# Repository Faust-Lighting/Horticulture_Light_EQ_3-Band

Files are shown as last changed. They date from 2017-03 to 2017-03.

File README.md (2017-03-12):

# Faust Lighting EQ 3-Band Horticulture Light 
[Faust Lighting](http://faustlighting.com/)

EQ is a Wifi enabled 2ft linear grow light.  The light spectrum and on/off schedule can be customized for specific plant species by programming the 3-band LED module.  A durable powder-coated heat sink ensures long lasting performance in demanding environments, while the beautiful walnut trim allows EQ to blend seamlessly into your home decor. 

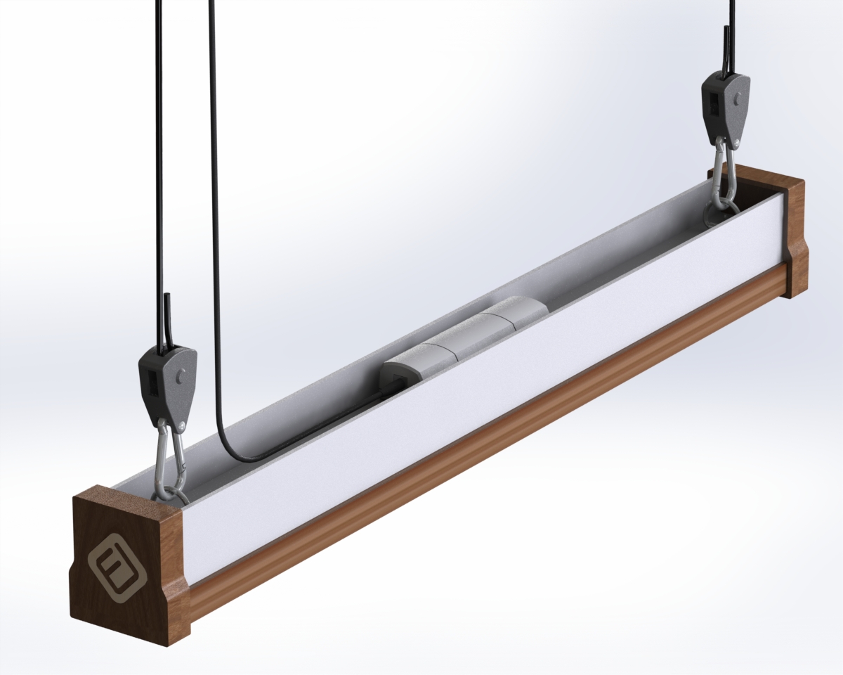
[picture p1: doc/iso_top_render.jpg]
Iso Render

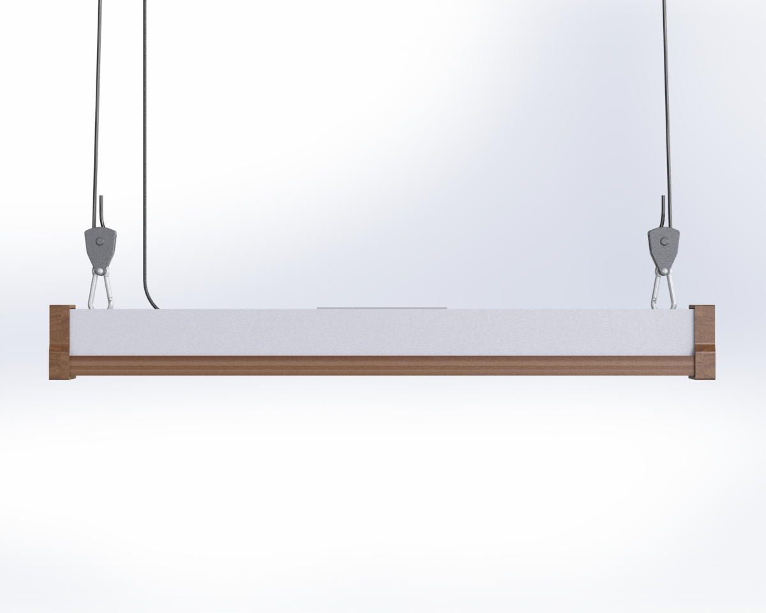
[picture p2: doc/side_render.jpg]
Side Render

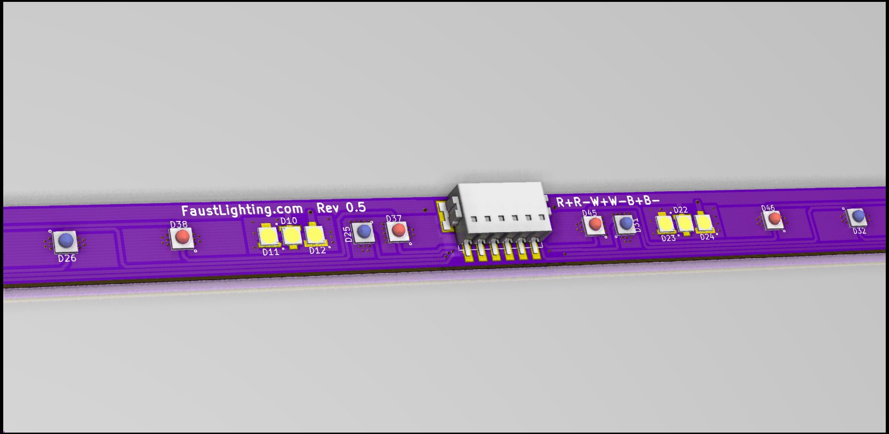
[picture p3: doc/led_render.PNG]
LED Render

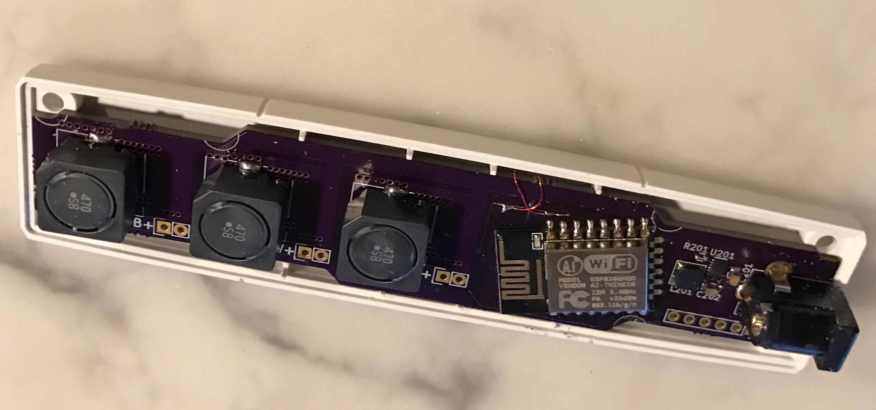
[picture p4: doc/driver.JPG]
Driver Photo


**Features**

* Tunable 3-Band Spectrum
* Red:  660nm
* Blue:  450nm
* White:  3000K CCT 90 CRI
* WiFi Connectivity
* No hub required
* Programmable Scheduling
* Simple scheduling for on/off control
* Advanced event driven scheduling for plant growth stages
* Open Source Design
* Open software
* Open hardware

**Construction**

* Extruded aluminum heatsink with durable powdercoat finish
* Walnut trim accents and endcaps with clear satin finish
* High efficiency acrylic diffuser
* Adjustable rope ratchet hangers
* Impact resistant ABS enclosure for driver electronics

**Specifications**

* Input Voltage:  90-265VAC, 50/60Hz
* Power Consumption:  40W typical (varies with spectrum)
* Dimensions:  24.98" (L) x 2.63" (W) x 2.81" (H)
* Weight:  3.0 lbs

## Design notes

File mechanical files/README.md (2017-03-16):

# Mechanical Change Log 
[Faust Lighting](http://faustlighting.com/)

**ASM1001**
* Current Revision: 0.2
  * Change Description: Moved wire routing slot on EXT1003, replaced model of HSG1001 with the manufacturer provided model.

* Previous Revision: 0.1
  * Change Description: Initial GitHub release.

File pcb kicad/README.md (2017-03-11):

# PCB Change Log 
[Faust Lighting](http://faustlighting.com/)

**Driver Board**
* Current Revision 0.4

**LED Board**
* Current Revision 0.6

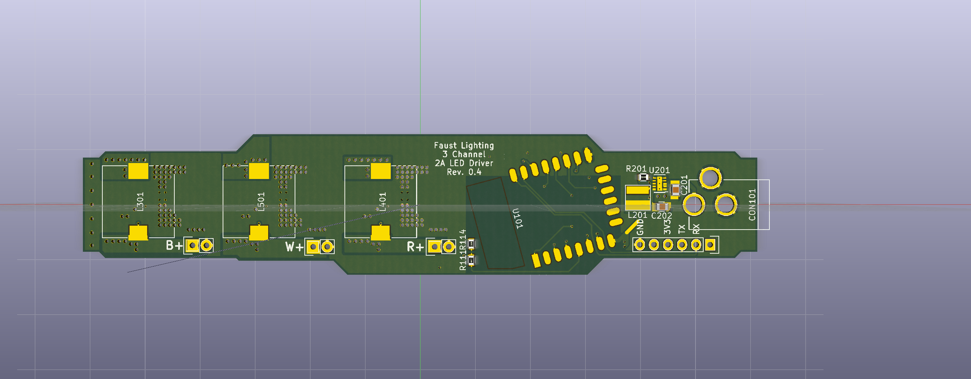
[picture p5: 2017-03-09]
pcb kicad/led_driver/3 channel led driver rev 0.4/top render.png

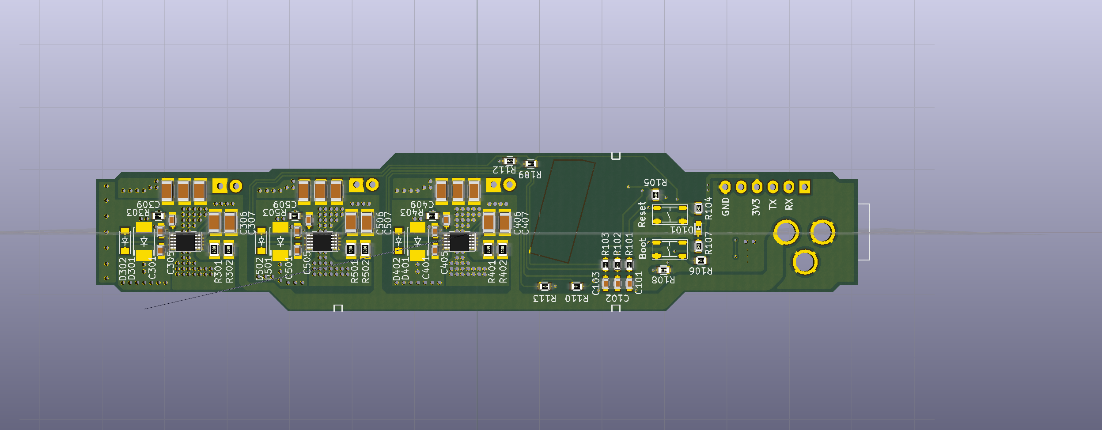
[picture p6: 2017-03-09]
pcb kicad/led_driver/3 channel led driver rev 0.4/bottom render.png

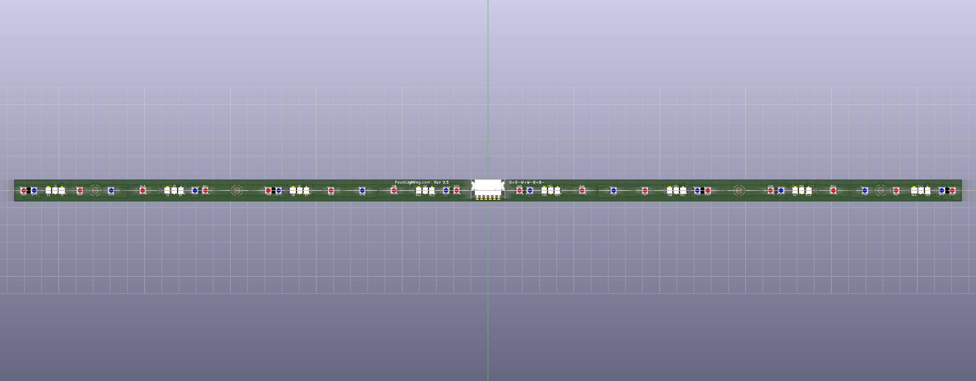
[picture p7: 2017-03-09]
pcb kicad/led_emitters/led emitter rev 0.6/light/front render.png

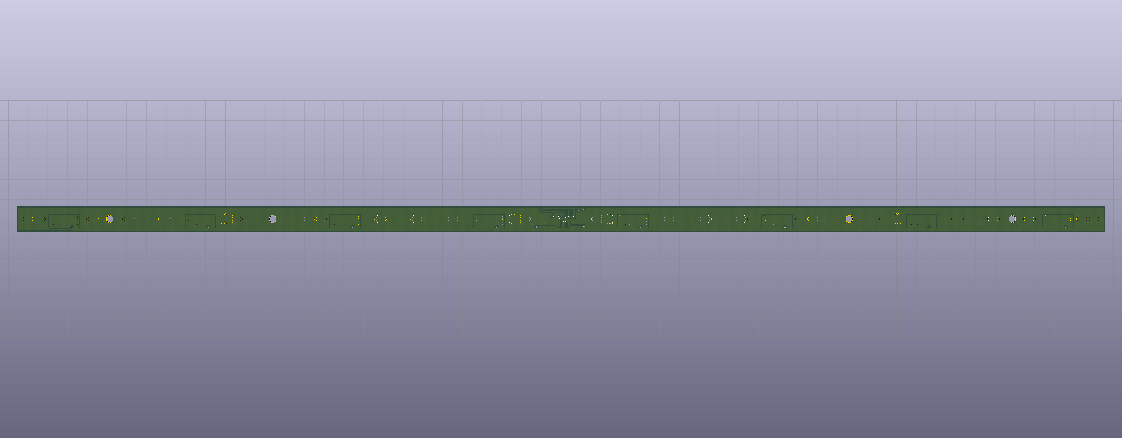
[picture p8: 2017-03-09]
pcb kicad/led_emitters/led emitter rev 0.6/light/back render.png

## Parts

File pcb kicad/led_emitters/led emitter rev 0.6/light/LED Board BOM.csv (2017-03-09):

Title | Grow Light - LED Board | Ref | Qty | Value | Footprint | Manufacturer | Manufacturer_Part_# | Mouser_Part_#
Revision | 0.5 | D1 D2 D3 D4 D5 D6 D7 D8 D9 D10 D11 D12 D15 D14 D13 D16 D17 D18 D21 D20 D19 D22 D23 D24 | 24 | White_LED | junes:MP3030 | Luminus | MP-3030-2200-30-90 | 896-MP303022003090
Date | 1/20/2017 | D37 D38 D39 D40 D41 D42 D43 D44 D45 D46 D47 D48 D49 D50 D51 D52 | 16 | Deep Red 660nm | junes:Deep_Red_660nm | Luminus | SST-10-DR-B90-H660 | 896-SST10DRB90H660
Generated | 1/19/2017 23:50 | D25 D26 D27 D28 D29 D30 D31 D32 D33 D34 D35 D36 | 12 | Blue 450nm | junes:Blue_450nm | Luminus | SST-10-B-B90-P450 | 896-SST10BB90P450
Company | Faust Light | P1 | 1 | CONN_02X03 | junes:1814676 | Phoenix Contact | 1814676 | 651-1814676
Comment 1
Comment 2
Comment 3
Comment 4
Total Parts | 53
Total Unique Parts | 4
Generated 1/19/2017 11:50:32 PM

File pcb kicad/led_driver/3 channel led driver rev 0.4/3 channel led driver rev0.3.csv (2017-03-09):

Title | ESP-8226 Controlled 3 Channel Led Driver 2A Max
Revision | 0.5
Date
Generated | 1/24/2017 15:12
Company
Comment 1
Comment 2
Comment 3
Comment 4
Total Parts | 70
Total Unique Parts | 25
Ref | Qty | Value | Footprint | Manufacturer | Manufacturer_Part_# | Mouser_Part_# | Notes
C101 C102 C103 | 3 | 10uF | Capacitors_SMD:C_0603 | Murata Electronics | GRM188R60J106KE47D | 81-GRM188R60J106KE7D | 6.3V X5R 10%
C201 | 1 | 2.2uF | Capacitors_SMD:C_0805 | Murata Electronics | GRM21BR61E225KA12L | 81-GRM21R61E225KA12L | 25V X5R 10%
C202 | 1 | 22.0uF | Capacitors_SMD:C_0805 | Murata Electronics | 81-GRM21R60J226ME39L | 81-GRM21R60J226ME39L | 6.3V X5R 20%
C301 C401 C501 | 3 | 0.1uF | Capacitors_SMD:C_0603 | Murata | GCM188R71C104KA37J | 81-GCM188R71C104KA7J | 16V X7R 10%
C309 C409 C509 | 3 | 470pF | Capacitors_SMD:C_0603 | Murata Electronics | GRM033R71H471KA12D | 81-GRM033R71H471KA2D | 50V X7R 10%
C305 C405 C505 | 3 | 1uF | Capacitors_SMD:C_0603 | Murata | GCM188R71C105KA64D | 81-GCM188R71C105K64D | 16V X7R 10%
C306 C307 C302 C303 C304 C406 C407 C402 C403 C404 C506 C507 C502 C503 C504 | 15 | 2.2uF | Capacitors_SMD:C_0805 | Murata Electronics | GRM21BR61E225KA12L | GRM21BR61E225KA12L | 25V X5R 10%
CON101 | 1 | BARREL_JACK | junes:Barrel_Jack_Wurth_694106301002 | Wurth Electronics | 6.94106E+11 | 710-694106301002
D101 | 1 | LED | LEDs:LED-0603 | Lite-On | LTST-C190KRKT | 859-LTST-C190KRKT
D302 D402 D502 | 3 | 100V 200mA | Diodes_SMD:SOD-123 | ON Semi | MMSD4148T1G | 863-MMSD4148T1G | 100V 0.2A
D301 D401 D501 | 3 | 100V 3A | Diodes_SMD:SOD-128-2 | NXP | PMEG10030ELPX | 771-PMEG10030ELPX | 100V 3A
L201 | 1 | 10uH | junes:VLS4012ET-100M | TDK | VLS4012ET-100M | 810-VLS4012ET-100M | 20% 500mA+ 228mOhms
L301 L401 L501 | 3 | 47uH | junes:MBH12575C | Murata - TOKO | MBH12575C-470MA=P3 | 81-MBH12575C-470MAP3 | 2.7A 53mOhms 20%
P101 | 1 | CONN_01X06 | Pin_Headers:Pin_Header_Straight_1x06
P1 P2 P3 | 3 | CONN_01X02 | Pin_Headers:Pin_Header_Straight_1x02
R101 R102 R107 R103 | 4 | 1K | Resistors_SMD:R_0603
R104 R105 R106 | 3 | 10K | Resistors_SMD:R_0603
R108 | 1 | 10K | Resistors_SMD:R_0603
R201 | 1 | 100K | Resistors_SMD:R_0603 |  |  |  | 1% Tolerence
R302 R301 R402 R401 R502 R501 | 6 | 0.27 | Resistors_SMD:R_0805 | Susumu | KRL1220E-M-R270-F-T5 | 754-KRL1220EMR270FT5 | 1%
R303 R403 R503 | 3 | 48.7k | Resistors_SMD:R_0603 | Vishay | CRCW060348K7FKEA | 71-CRCW0603-48.7K-E3 | 1%
SW102 SW101 | 2 | TACT_4.2MM | MF_Switches:MF_Switches-TACT4.2MM | C&K Components | PTS810 SJK 250 SMTR LFS | 611-PTS810SJK250SMTR
U101 | 1 | ESP8266-12E | ESP8266:ESP-12E | ESPRESSIF | ESP8266-12E | 485-2491
U201 | 1 | TPS62177 | junes:TPS62177 | Texas Instruments | TPS62177DQCR | 595-TPS62177DQCR
U301 U401 U501 | 3 | TPS92515 | junes:TPS92515x | Texas Instruments | TPS92515DGQR | 595-TPS92515DGQR
BOM made with KICAD_BOM_WIZARD (https://github.com/HashDefineElectronics/KiCad_BOM_Wizard.git)
Generated 1/24/2017 3:12:45 PM

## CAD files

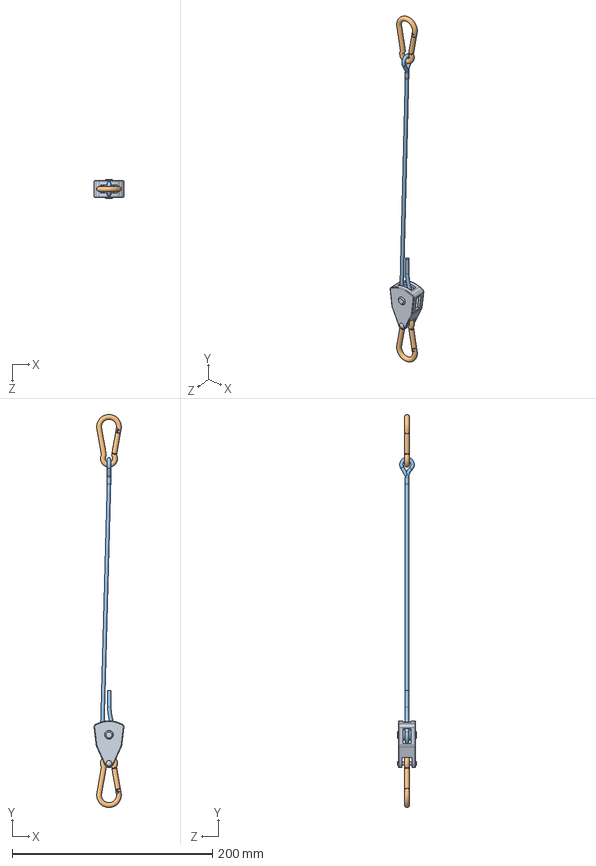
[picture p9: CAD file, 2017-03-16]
mechanical files/asm1001 rev 0.2/ASM1001 Rev 0.2 SOLIDWORKS/MIS1003.SLDASM
29.9 x 393.0 x 19.3 mm
MIS1003-2
MIS1003-3 x 2
MIS1003-1

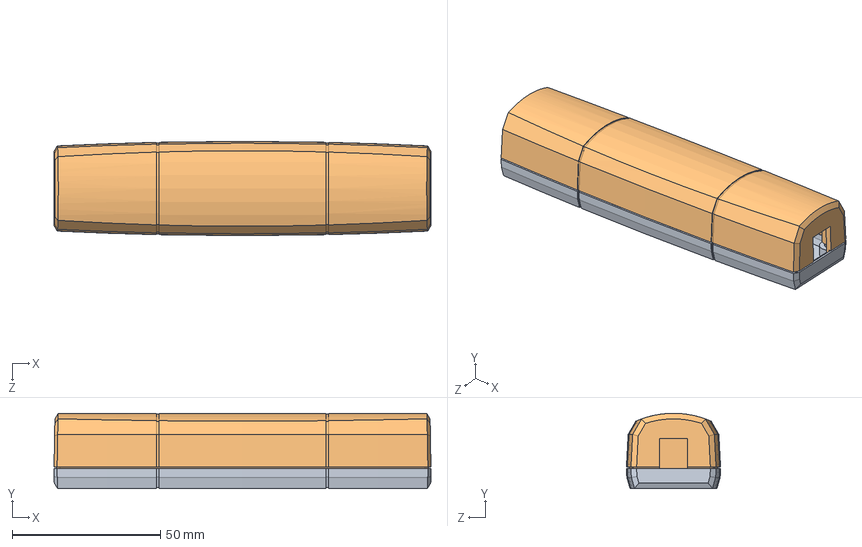
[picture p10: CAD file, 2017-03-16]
mechanical files/asm1001 rev 0.2/ASM1001 Rev 0.2 SOLIDWORKS/HSG1001.SLDASM
127.0 x 25.4 x 31.8 mm
HSG1001-1
HSG1001-2

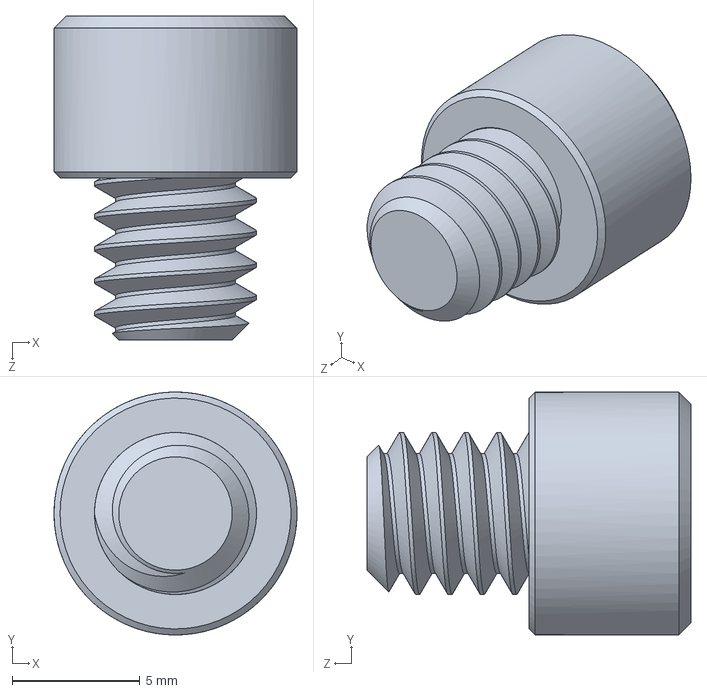
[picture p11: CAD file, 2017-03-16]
mechanical files/asm1001 rev 0.2/ASM1001 Rev 0.2 SOLIDWORKS/FST1002.SLDPRT
9.53 x 9.52 x 12.7 mm

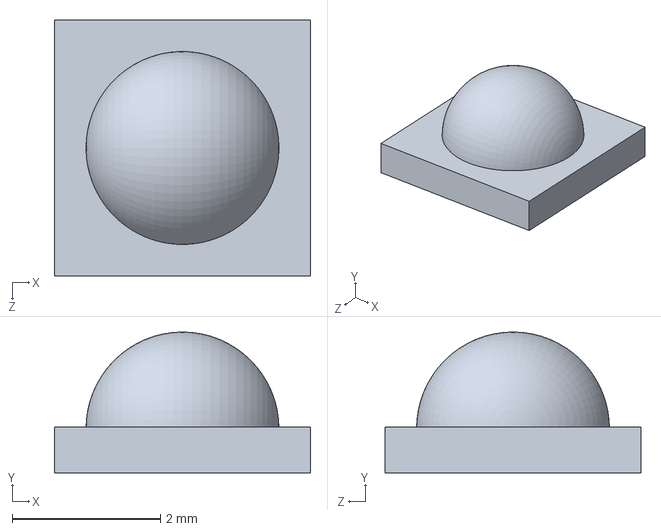
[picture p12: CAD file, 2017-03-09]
pcb kicad/led_emitters/led emitter rev 0.6/3D files/red led.SLDPRT
3.45 x 1.90 x 3.45 mm

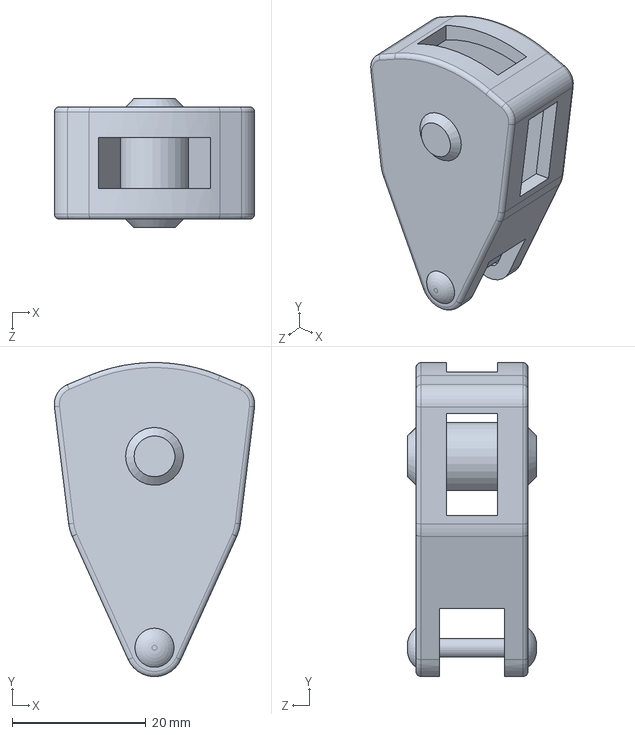
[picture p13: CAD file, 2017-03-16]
mechanical files/asm1001 rev 0.2/ASM1001 Rev 0.2 SOLIDWORKS/MIS1003-2.SLDPRT
29.9 x 46.9 x 19.3 mm

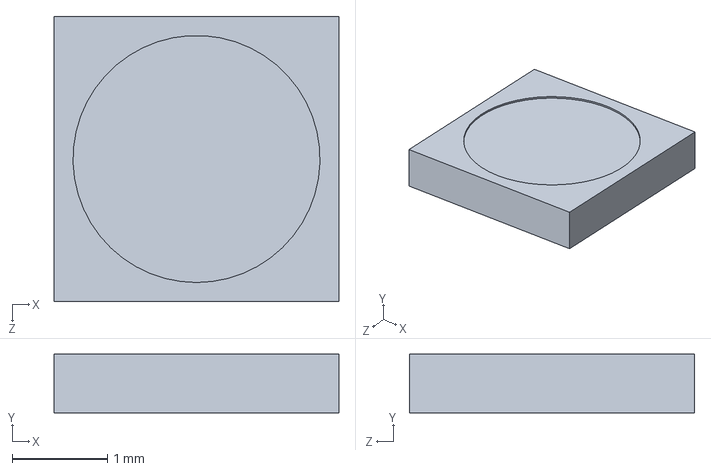
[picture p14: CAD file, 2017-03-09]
pcb kicad/led_emitters/led emitter rev 0.6/3D files/white led.SLDPRT
3.00 x 0.62 x 3.00 mm

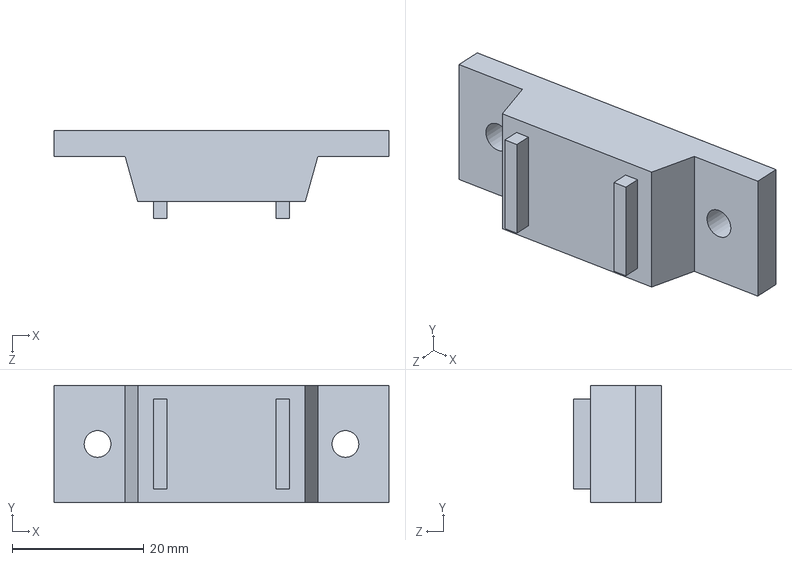
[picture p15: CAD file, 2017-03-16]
mechanical files/asm1001 rev 0.2/ASM1001 Rev 0.2 SOLIDWORKS/MIS1001.SLDPRT
50.8 x 17.8 x 13.3 mm

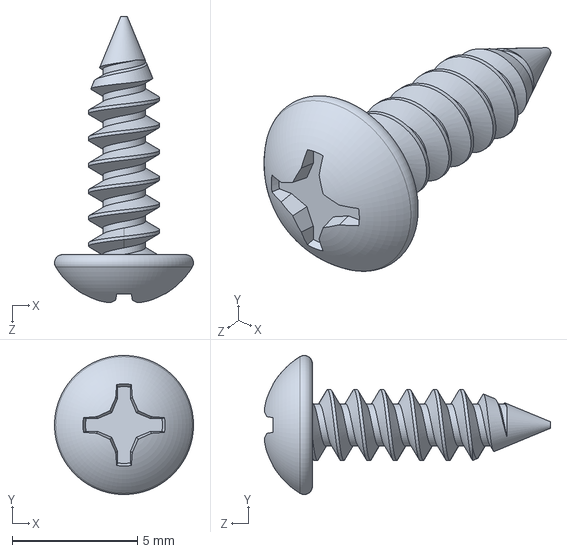
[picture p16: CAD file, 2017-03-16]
mechanical files/asm1001 rev 0.2/ASM1001 Rev 0.2 SOLIDWORKS/FST1004.SLDPRT
5.56 x 5.56 x 11.5 mm

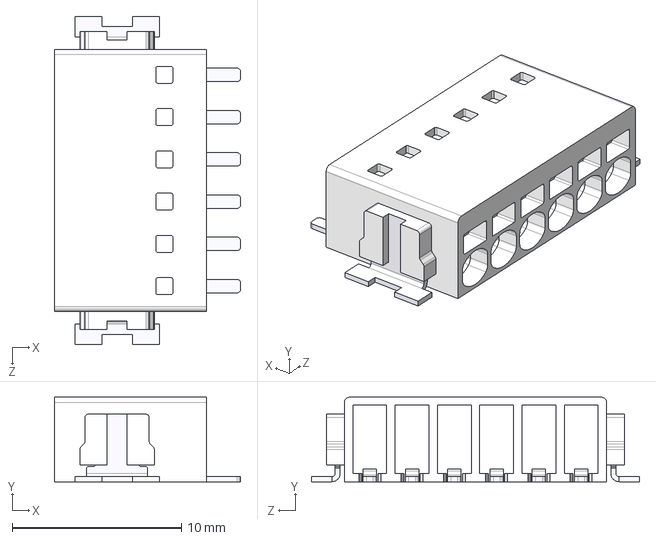
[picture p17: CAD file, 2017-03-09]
pcb kicad/led_emitters/led emitter rev 0.6/3D files/PHOENIX CONTACT 1814676.STEP
11.0 x 5.00 x 19.4 mm

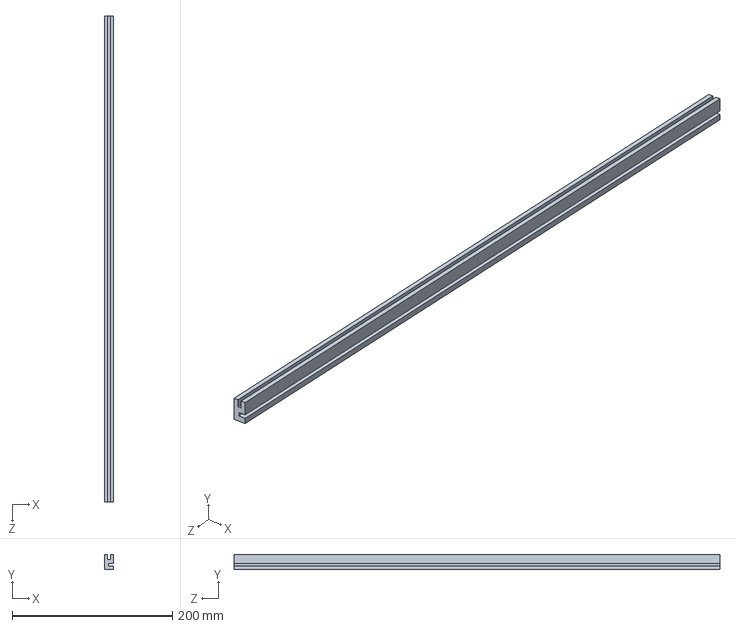
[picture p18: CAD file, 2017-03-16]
mechanical files/asm1001 rev 0.2/ASM1001 Rev 0.2 SOLIDWORKS/EXT1005.SLDPRT
11.1 x 19.1 x 606.4 mm

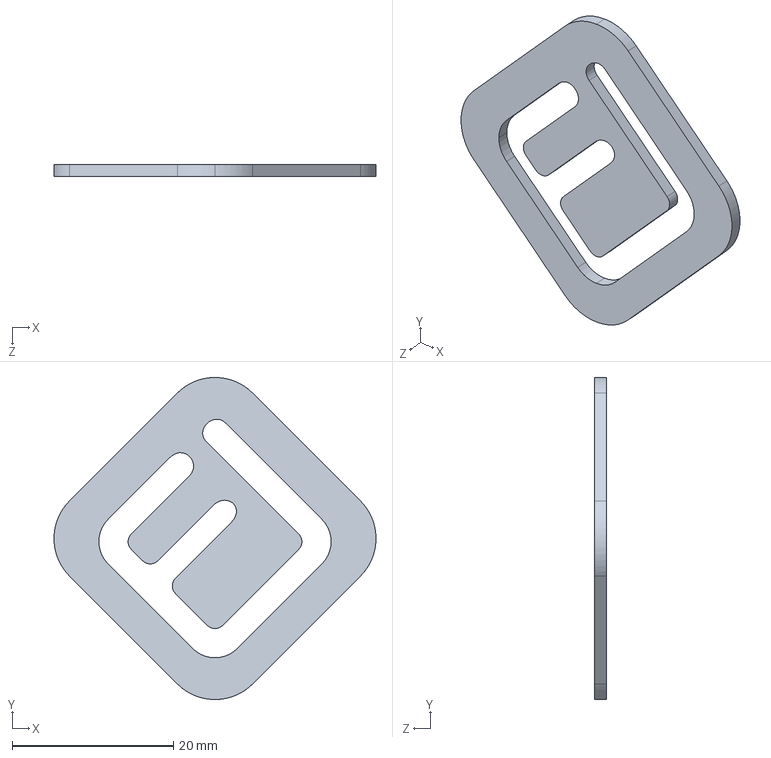
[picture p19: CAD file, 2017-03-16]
mechanical files/asm1001 rev 0.2/ASM1001 Rev 0.2 SOLIDWORKS/COV1002.SLDPRT
39.9 x 39.9 x 1.52 mm

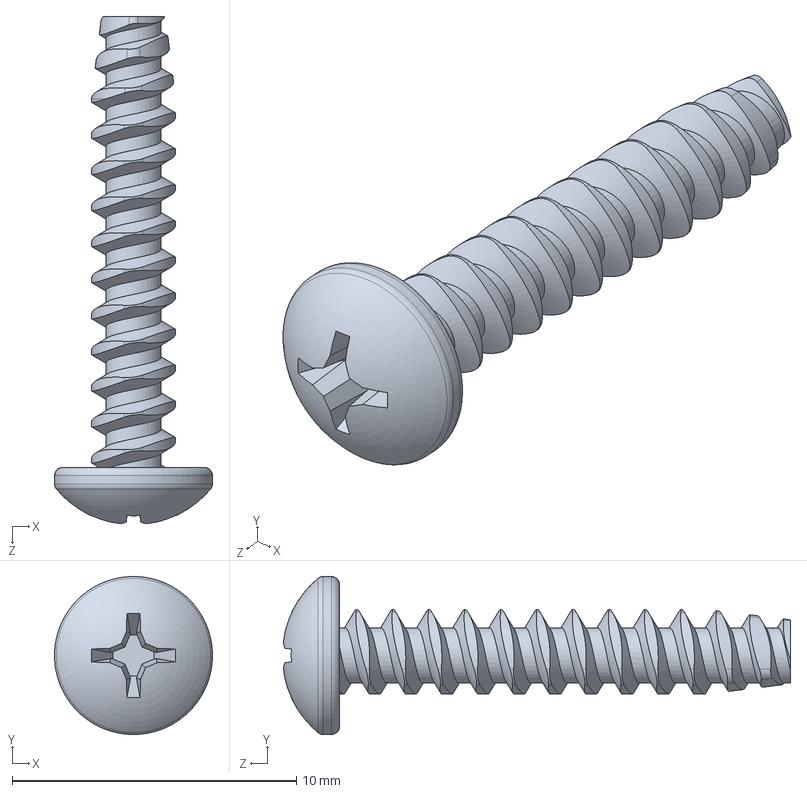
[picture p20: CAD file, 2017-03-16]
mechanical files/asm1001 rev 0.2/ASM1001 Rev 0.2 SOLIDWORKS/FST1003.SLDPRT
5.56 x 5.56 x 17.9 mm

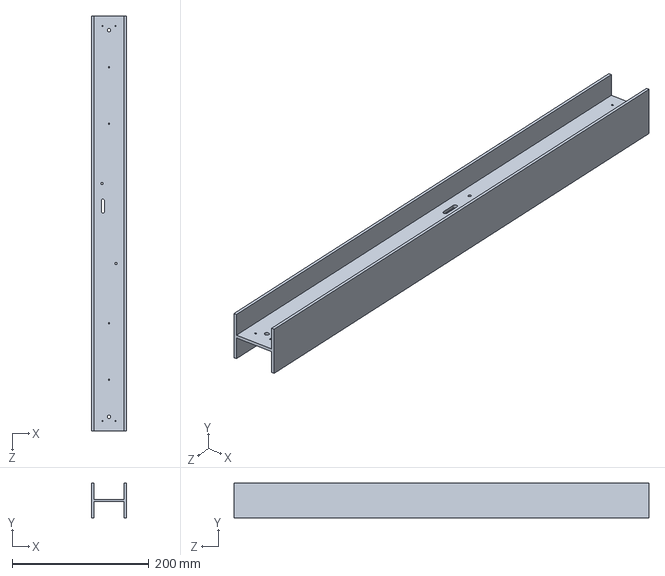
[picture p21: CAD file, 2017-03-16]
mechanical files/asm1001 rev 0.2/ASM1001 Rev 0.2 SOLIDWORKS/EXT1003.SLDPRT
50.8 x 50.8 x 606.4 mm

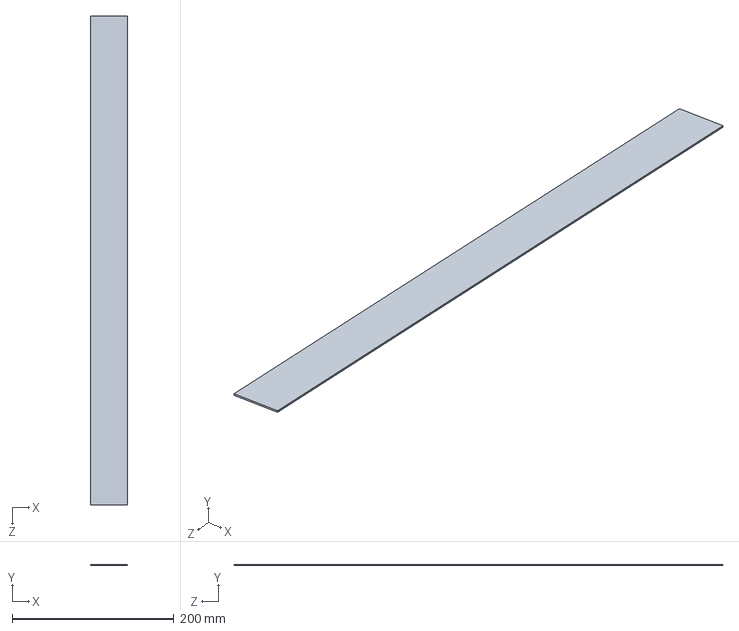
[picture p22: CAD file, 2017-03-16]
mechanical files/asm1001 rev 0.2/ASM1001 Rev 0.2 SOLIDWORKS/LEN1001.SLDPRT
46.2 x 1.52 x 605.0 mm

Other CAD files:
pcb kicad/led_emitters/led emitter rev 0.6/3D files/blue led.SLDPRT
mechanical files/asm1001 rev 0.2/ASM1001 Rev 0.2 SOLIDWORKS/PWR1003.SLDPRT
mechanical files/asm1001 rev 0.2/ASM1001 Rev 0.2 SOLIDWORKS/HSG1001-1.sldprt
mechanical files/asm1001 rev 0.2/ASM1001 Rev 0.2 SOLIDWORKS/FST1001.SLDPRT
mechanical files/asm1001 rev 0.2/ASM1001 Rev 0.2 SOLIDWORKS/BKT1002.SLDPRT
mechanical files/asm1001 rev 0.2/ASM1001 Rev 0.2 SOLIDWORKS/COV1001.SLDPRT
mechanical files/asm1001 rev 0.2/ASM1001 Rev 0.2 SOLIDWORKS/HSG1001-2.sldprt
mechanical files/asm1001 rev 0.2/ASM1001 Rev 0.2 SOLIDWORKS/MIS1003-1.SLDPRT
mechanical files/asm1001 rev 0.2/ASM1001 Rev 0.2 SOLIDWORKS/MIS1003-3.SLDPRT
mechanical files/asm1001 rev 0.2/ASM1001 Rev 0.2 SOLIDWORKS/PCB1002.SLDPRT
mechanical files/asm1001 rev 0.2/ASM1001 Rev 0.2 SOLIDWORKS/PCB1003.SLDPRT
mechanical files/asm1001 rev 0.2/ASM1001 Rev 0.2 SOLIDWORKS/REF1004.SLDPRT

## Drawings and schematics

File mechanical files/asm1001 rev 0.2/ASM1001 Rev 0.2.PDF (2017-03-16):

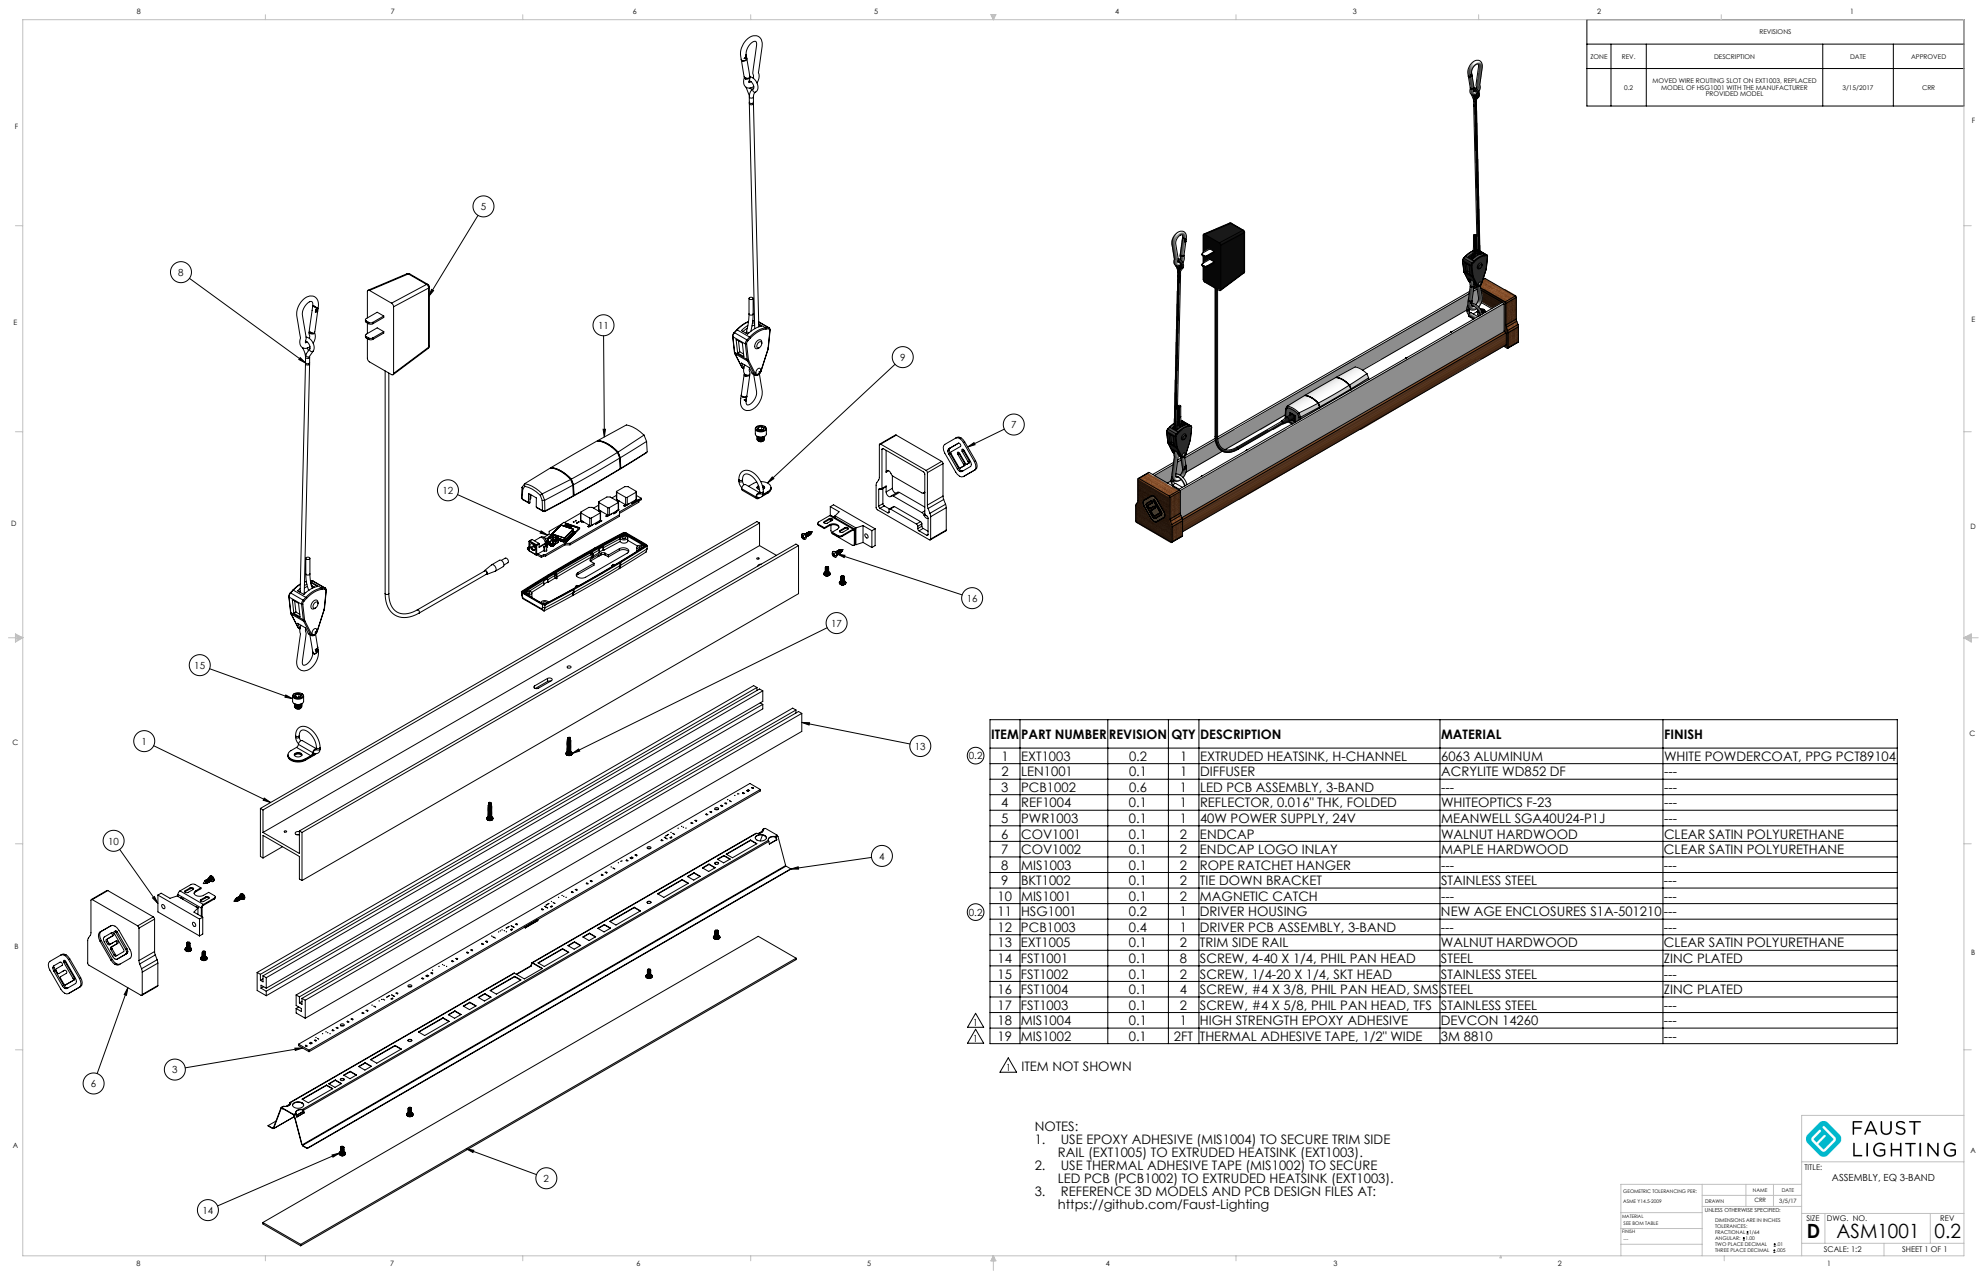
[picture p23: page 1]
1 ITEM NOT SHOWN; SHEET 1 OF 1; ASSEMBLY, EQ 3-BAND; SCALE: 1:2; DWG. NO.; REV; SEE BOM TABLE; TWO PLACE DECIMAL

ZONE | REV. | DESCRIPTION | DATE | APPROVED

0.2 | MOVED WIRE ROUTING SLOT ON EXT1003, REPLACED MODEL OF HSG1001 WITH THE MANUFACTURER PROVIDED MODEL | 3/15/2017 | CRR

ITEM PART NUMBER REVISION QTY DESCRIPTION | | | | | MATERIAL | FINISH
1 | EXT1003 | 0.2 | 1 | EXTRUDED HEATSINK, H-CHANNEL | 6063 ALUMINUM | WHITE POWDERCOAT, PPG PCT89104
2 | LEN1001 | 0.1 | 1 | DIFFUSER | ACRYLITE WD852 DF | ---
3 | PCB1002 | 0.6 | 1 | LED PCB ASSEMBLY, 3-BAND | --- | ---
4 | REF1004 | 0.1 | 1 | REFLECTOR, 0.016" THK, FOLDED | WHITEOPTICS F-23 | ---
5 | PWR1003 | 0.1 | 1 | 40W POWER SUPPLY, 24V | MEANWELL SGA40U24-P1J | ---
6 | COV1001 | 0.1 | 2 | ENDCAP | WALNUT HARDWOOD | CLEAR SATIN POLYURETHANE
7 | COV1002 | 0.1 | 2 | ENDCAP LOGO INLAY | MAPLE HARDWOOD | CLEAR SATIN POLYURETHANE
8 | MIS1003 | 0.1 | 2 | ROPE RATCHET HANGER | --- | ---
9 | BKT1002 | 0.1 | 2 | TIE DOWN BRACKET | STAINLESS STEEL | ---
10 | MIS1001 | 0.1 | 2 | MAGNETIC CATCH | --- | ---
11 | HSG1001 | 0.2 | 1 | DRIVER HOUSING | NEW AGE ENCLOSURES S1A-501210 ---
12 | PCB1003 | 0.4 | 1 | DRIVER PCB ASSEMBLY, 3-BAND | --- | ---
13 | EXT1005 | 0.1 | 2 | TRIM SIDE RAIL | WALNUT HARDWOOD | CLEAR SATIN POLYURETHANE
14 | FST1001 | 0.1 | 8 | SCREW, 4-40 X 1/4, PHIL PAN HEAD | STEEL | ZINC PLATED
15 | FST1002 | 0.1 | 2 | SCREW, 1/4-20 X 1/4, SKT HEAD | STAINLESS STEEL | ---
16 | FST1004 | 0.1 | 4 | SCREW, #4 X 3/8, PHIL PAN HEAD, SMS STEEL | | ZINC PLATED
17 | FST1003 | 0.1 | 2 | SCREW, #4 X 5/8, PHIL PAN HEAD, TFS | STAINLESS STEEL | ---
18 | MIS1004 | 0.1 | 1 | HIGH STRENGTH EPOXY ADHESIVE | DEVCON 14260 | ---
19 | MIS1002 | 0.1 | 2FT | THERMAL ADHESIVE TAPE, 1/2" WIDE | 3M 8810 | ---

NOTES:
1. USE EPOXY ADHESIVE (MIS1004) TO SECURE TRIM SIDE
RAIL (EXT1005) TO EXTRUDED HEATSINK (EXT1003).
2. USE THERMAL ADHESIVE TAPE (MIS1002) TO SECURE
LED PCB (PCB1002) TO EXTRUDED HEATSINK (EXT1003).
3. REFERENCE 3D MODELS AND PCB DESIGN FILES AT:
https://github.com/Faust-Lighting

GEOMETRIC TOLERANCING PER:
ASME Y14.5-2009

DRAWN
UNLESS OTHERWISE SPECIFIED:
DIMENSIONS ARE IN INCHES
TOLERANCES:
FRACTIONAL 1/64
ANGULAR: 1.00
THREE PLACE DECIMAL .005

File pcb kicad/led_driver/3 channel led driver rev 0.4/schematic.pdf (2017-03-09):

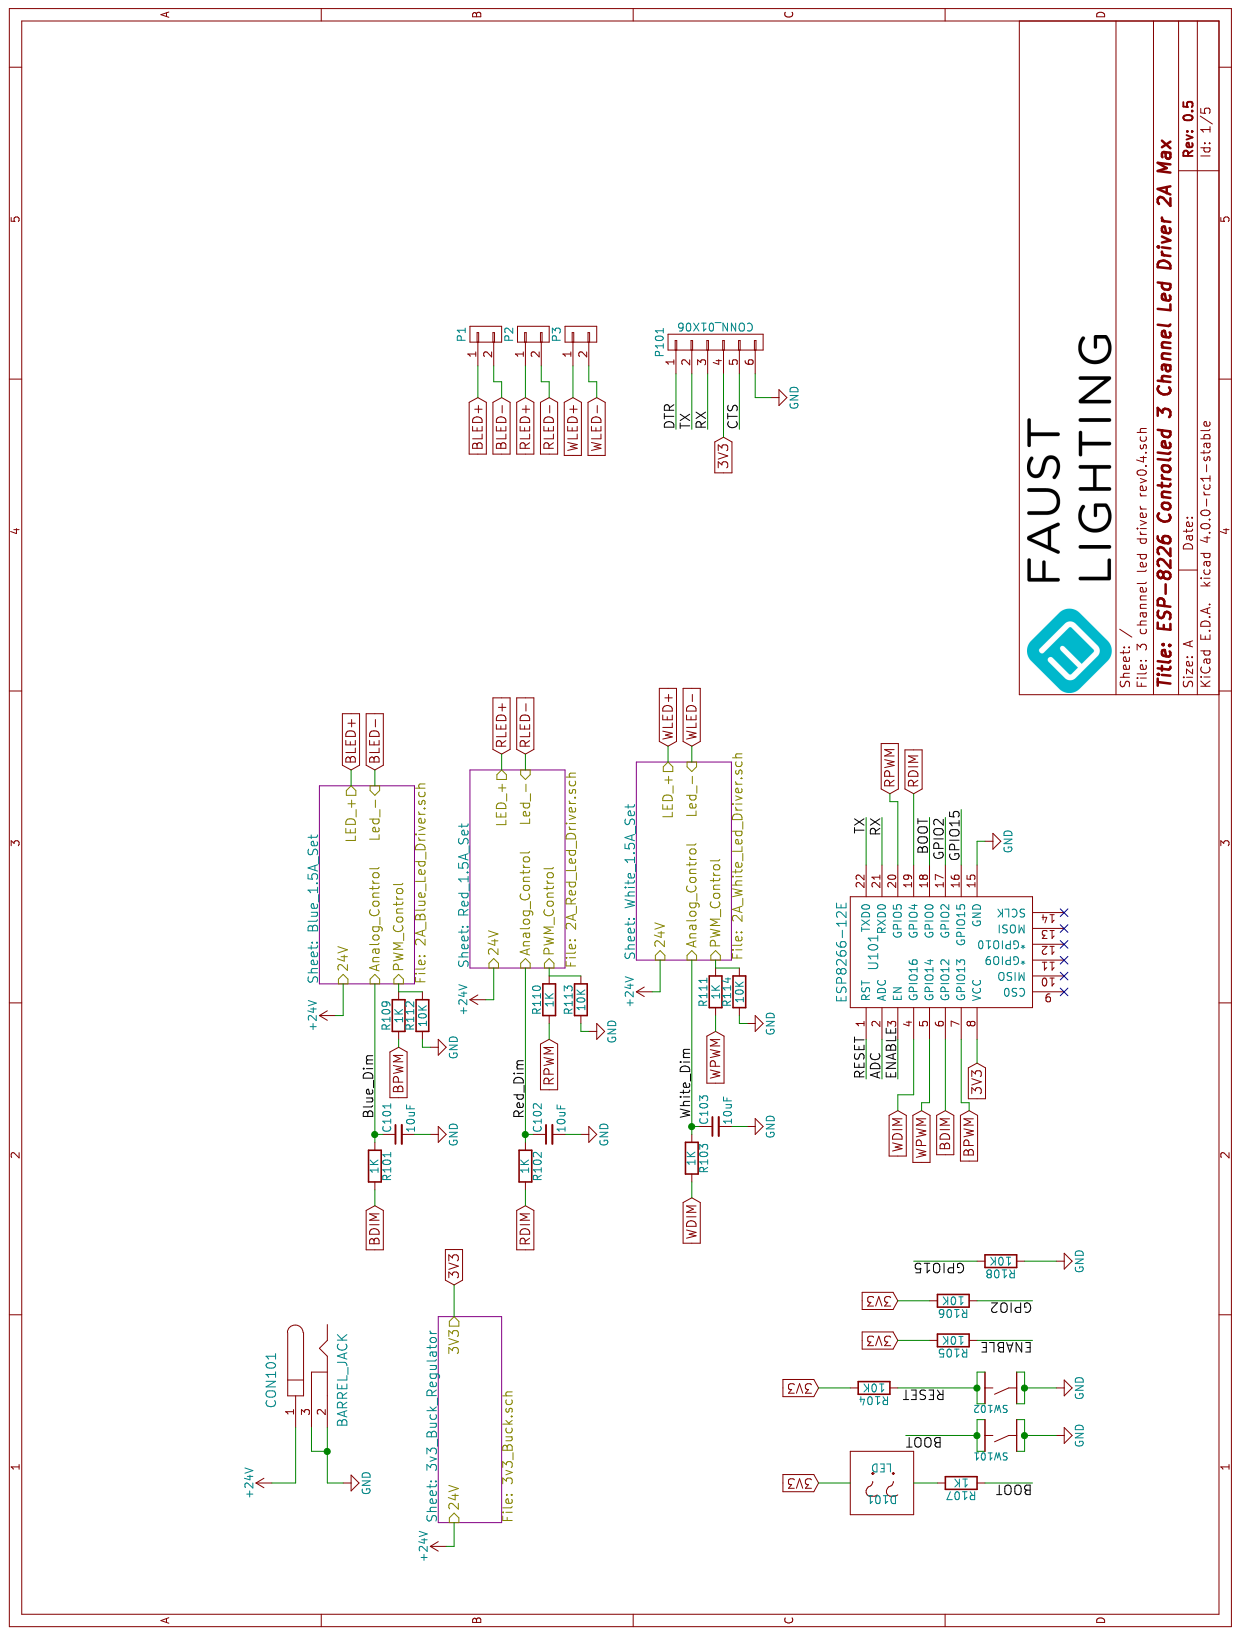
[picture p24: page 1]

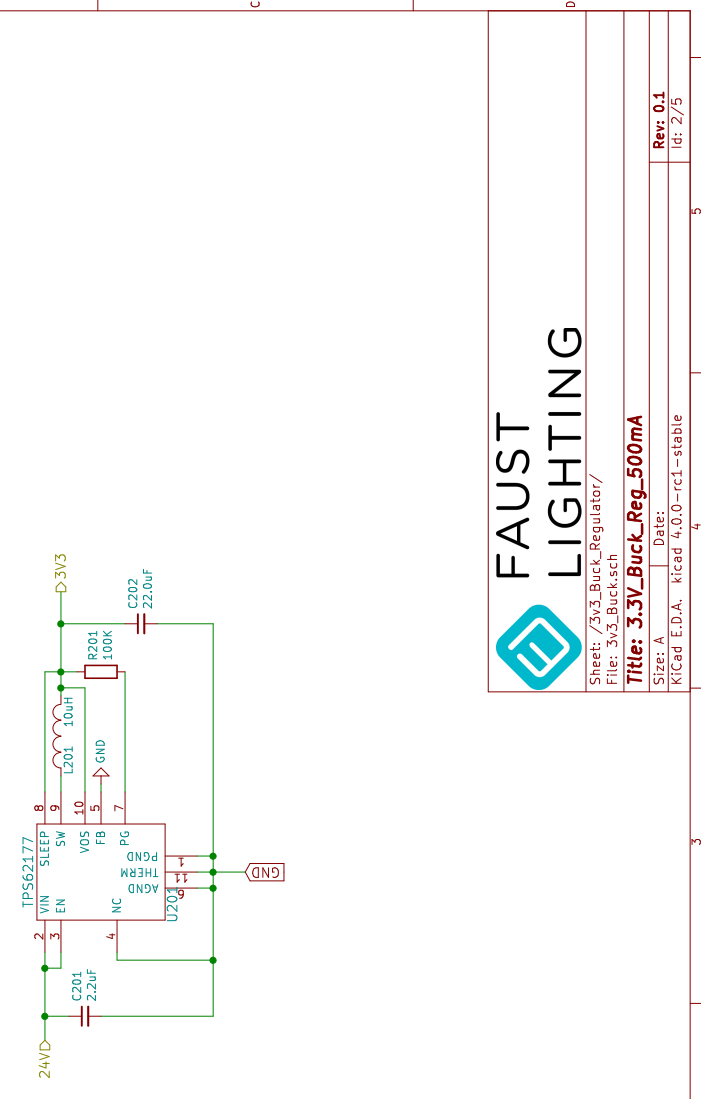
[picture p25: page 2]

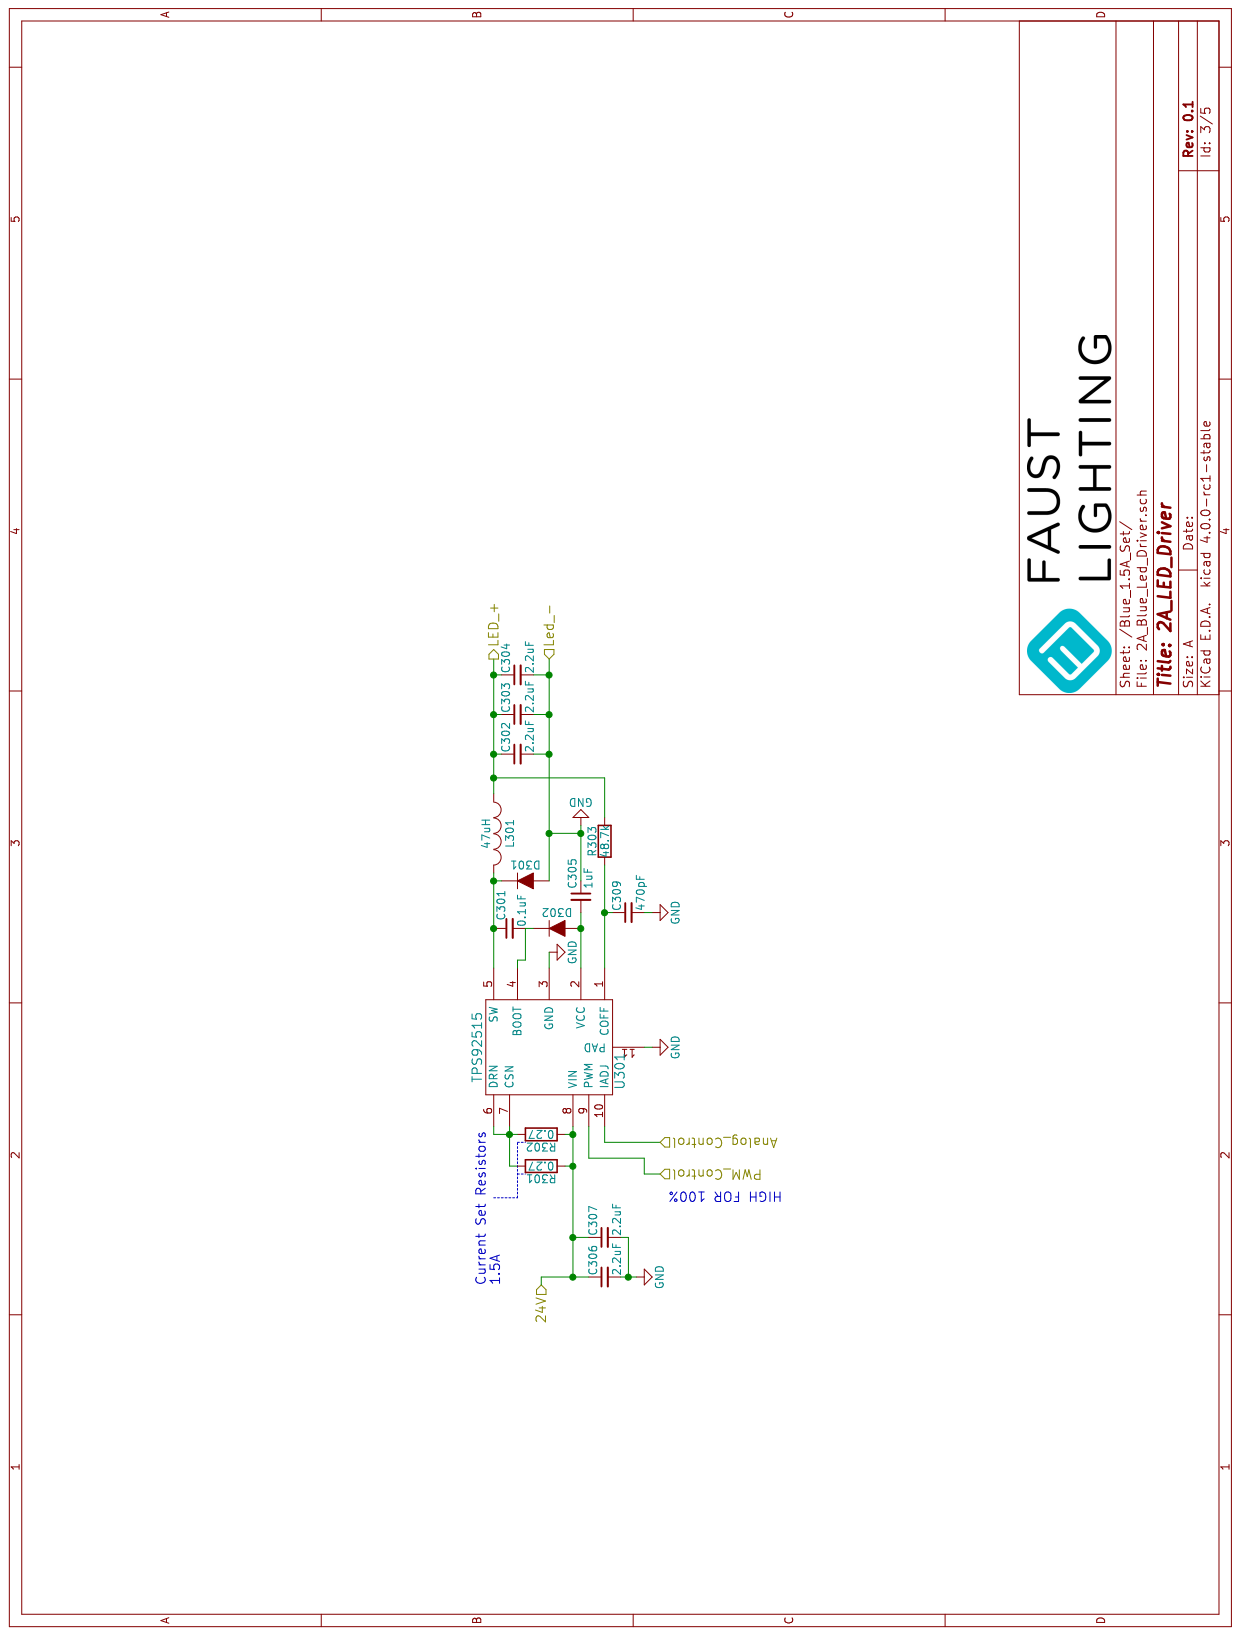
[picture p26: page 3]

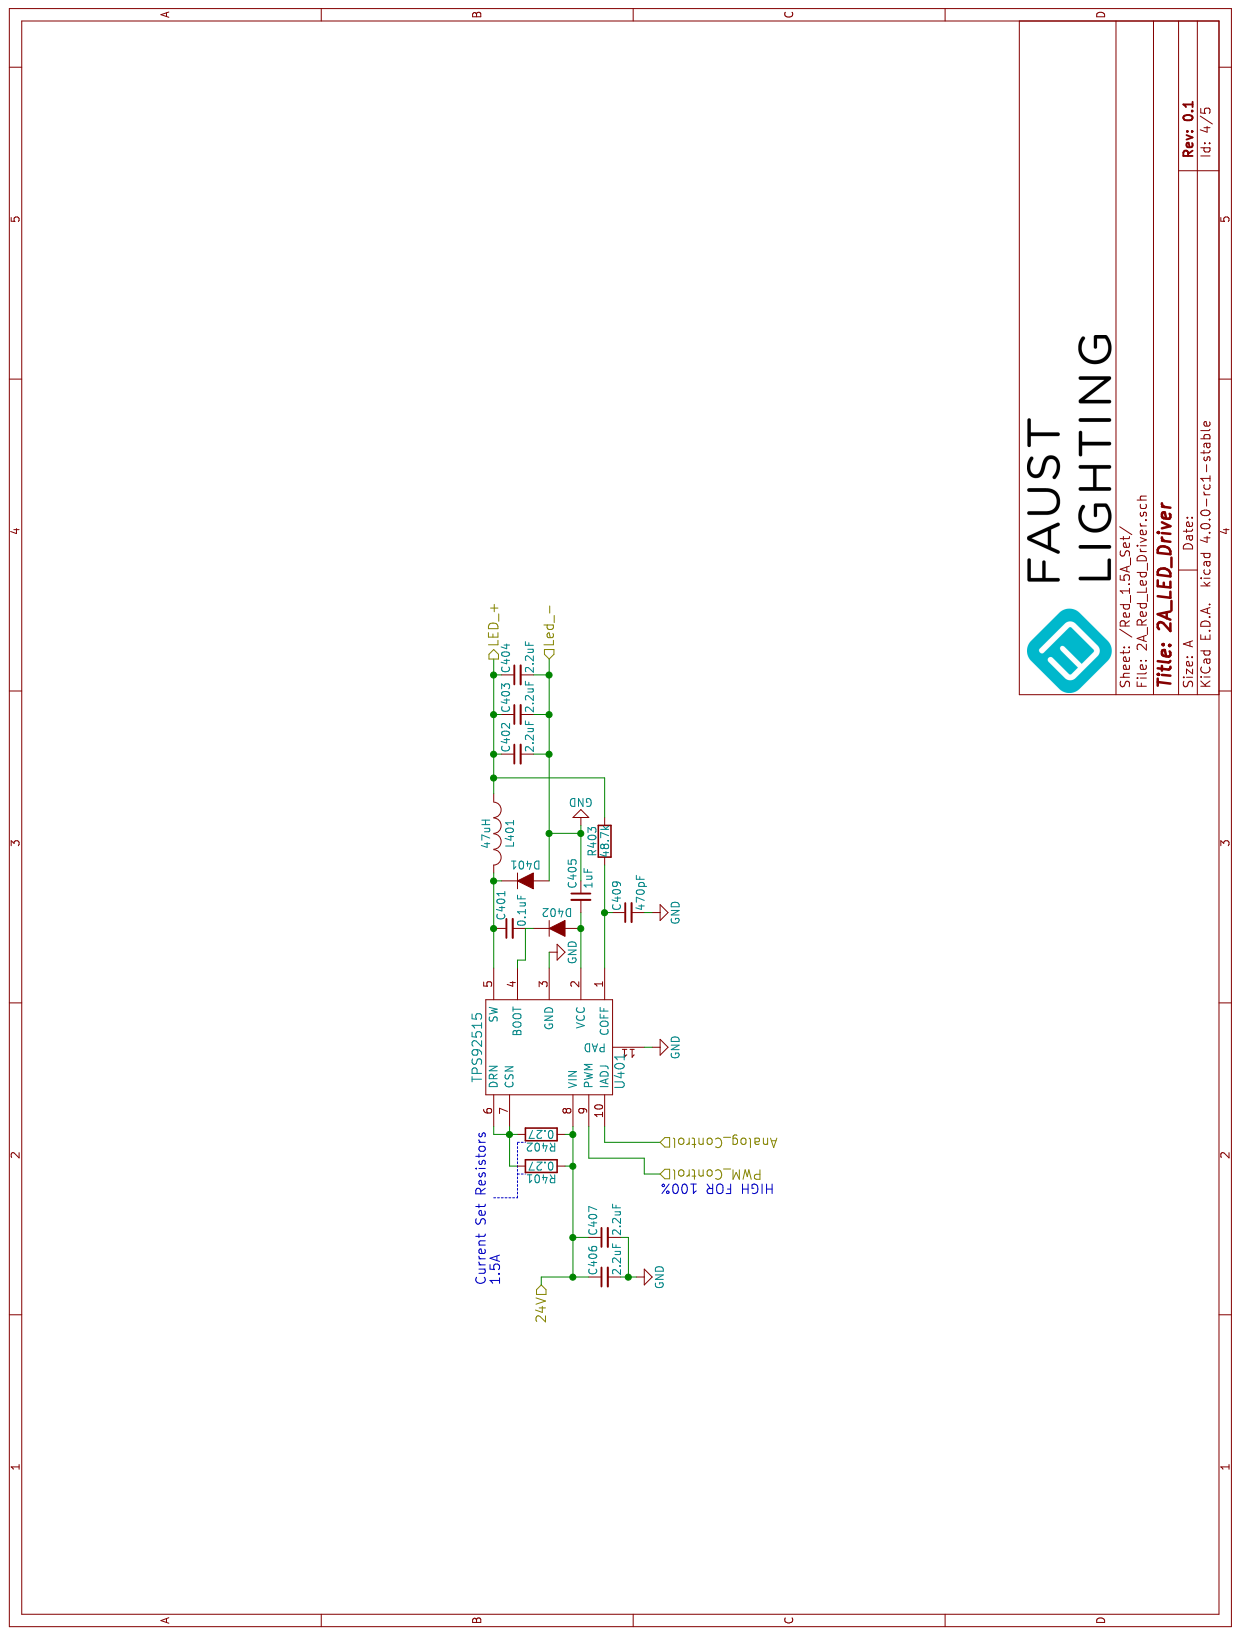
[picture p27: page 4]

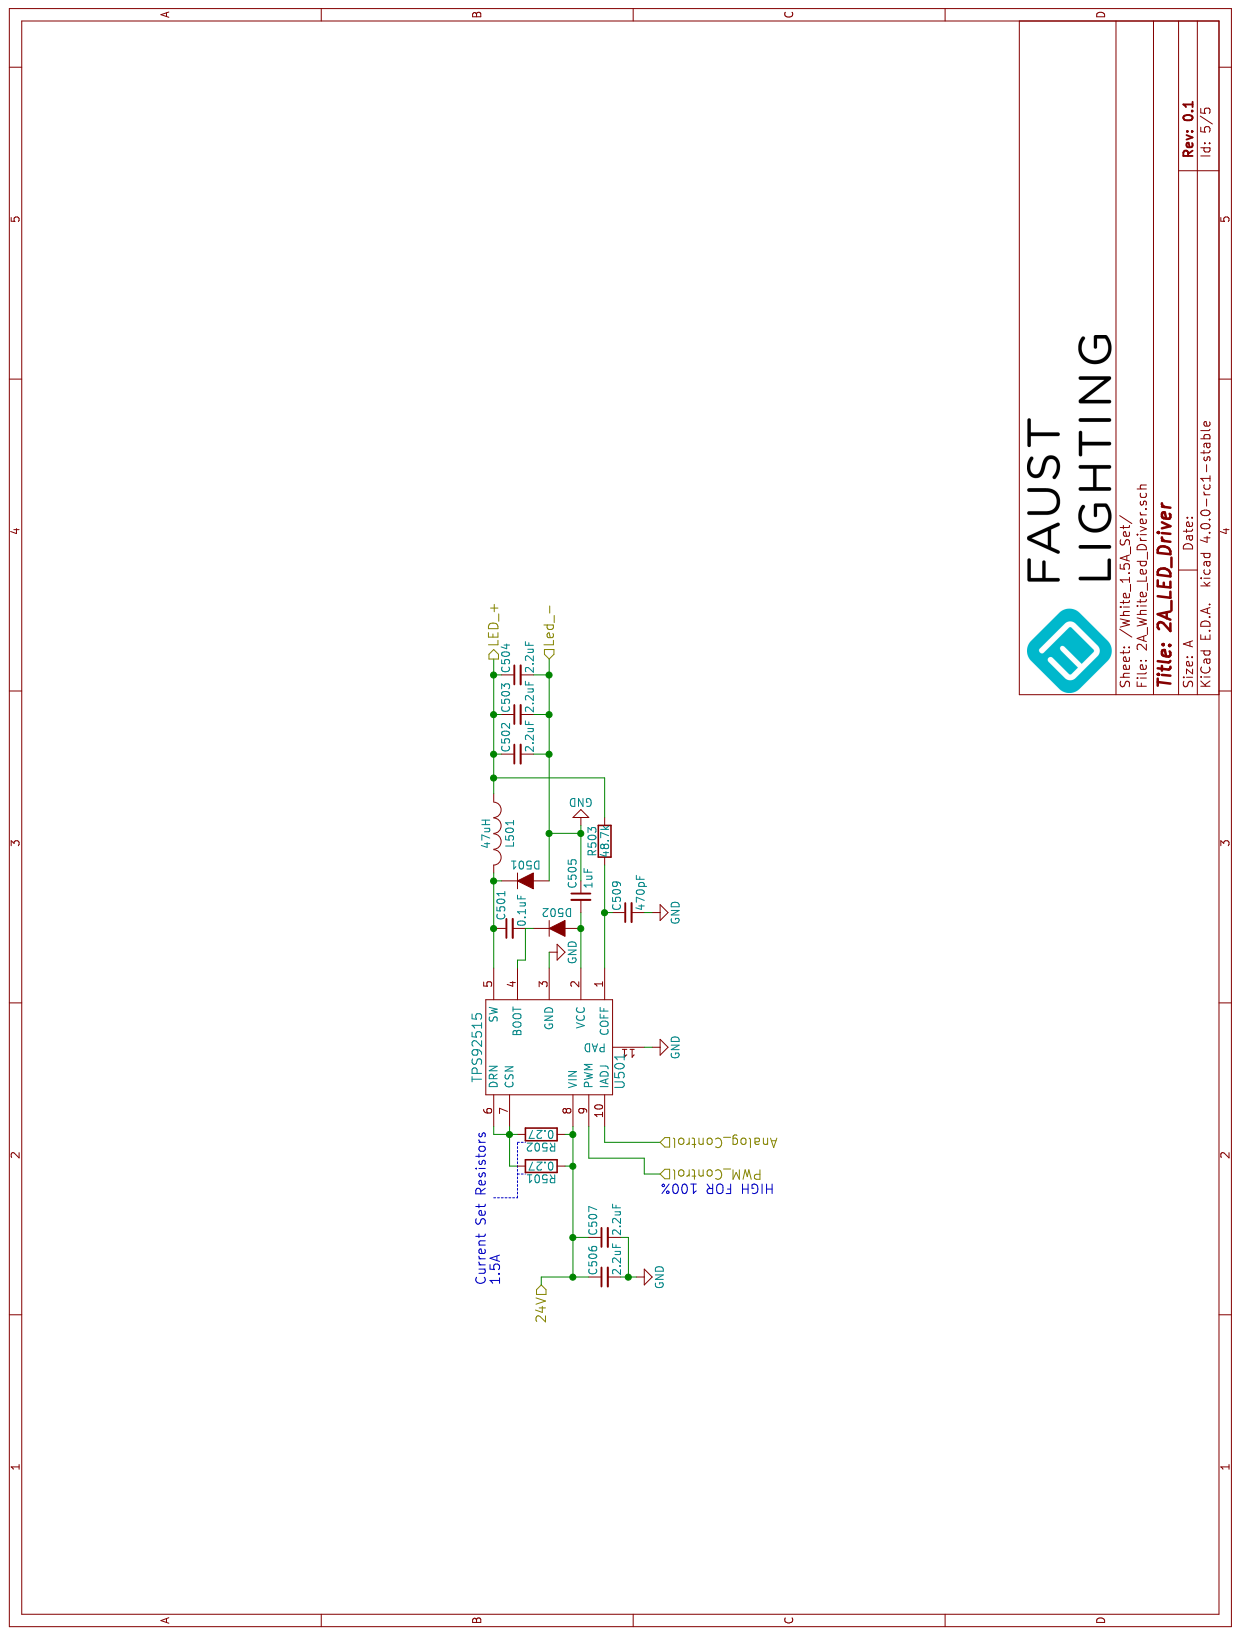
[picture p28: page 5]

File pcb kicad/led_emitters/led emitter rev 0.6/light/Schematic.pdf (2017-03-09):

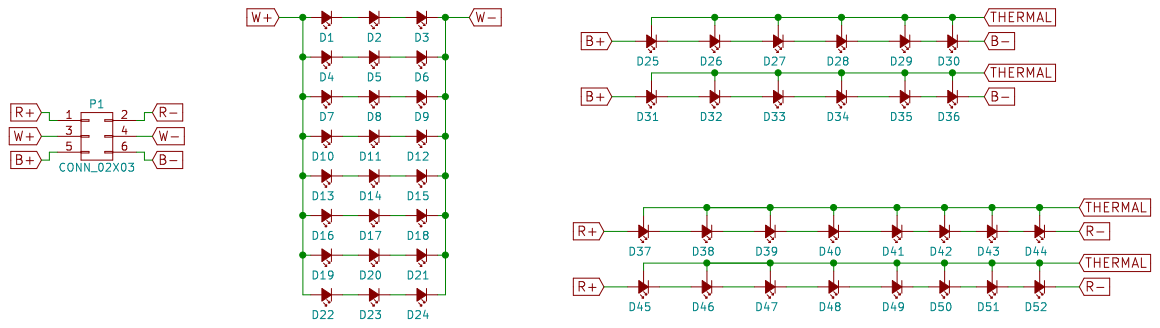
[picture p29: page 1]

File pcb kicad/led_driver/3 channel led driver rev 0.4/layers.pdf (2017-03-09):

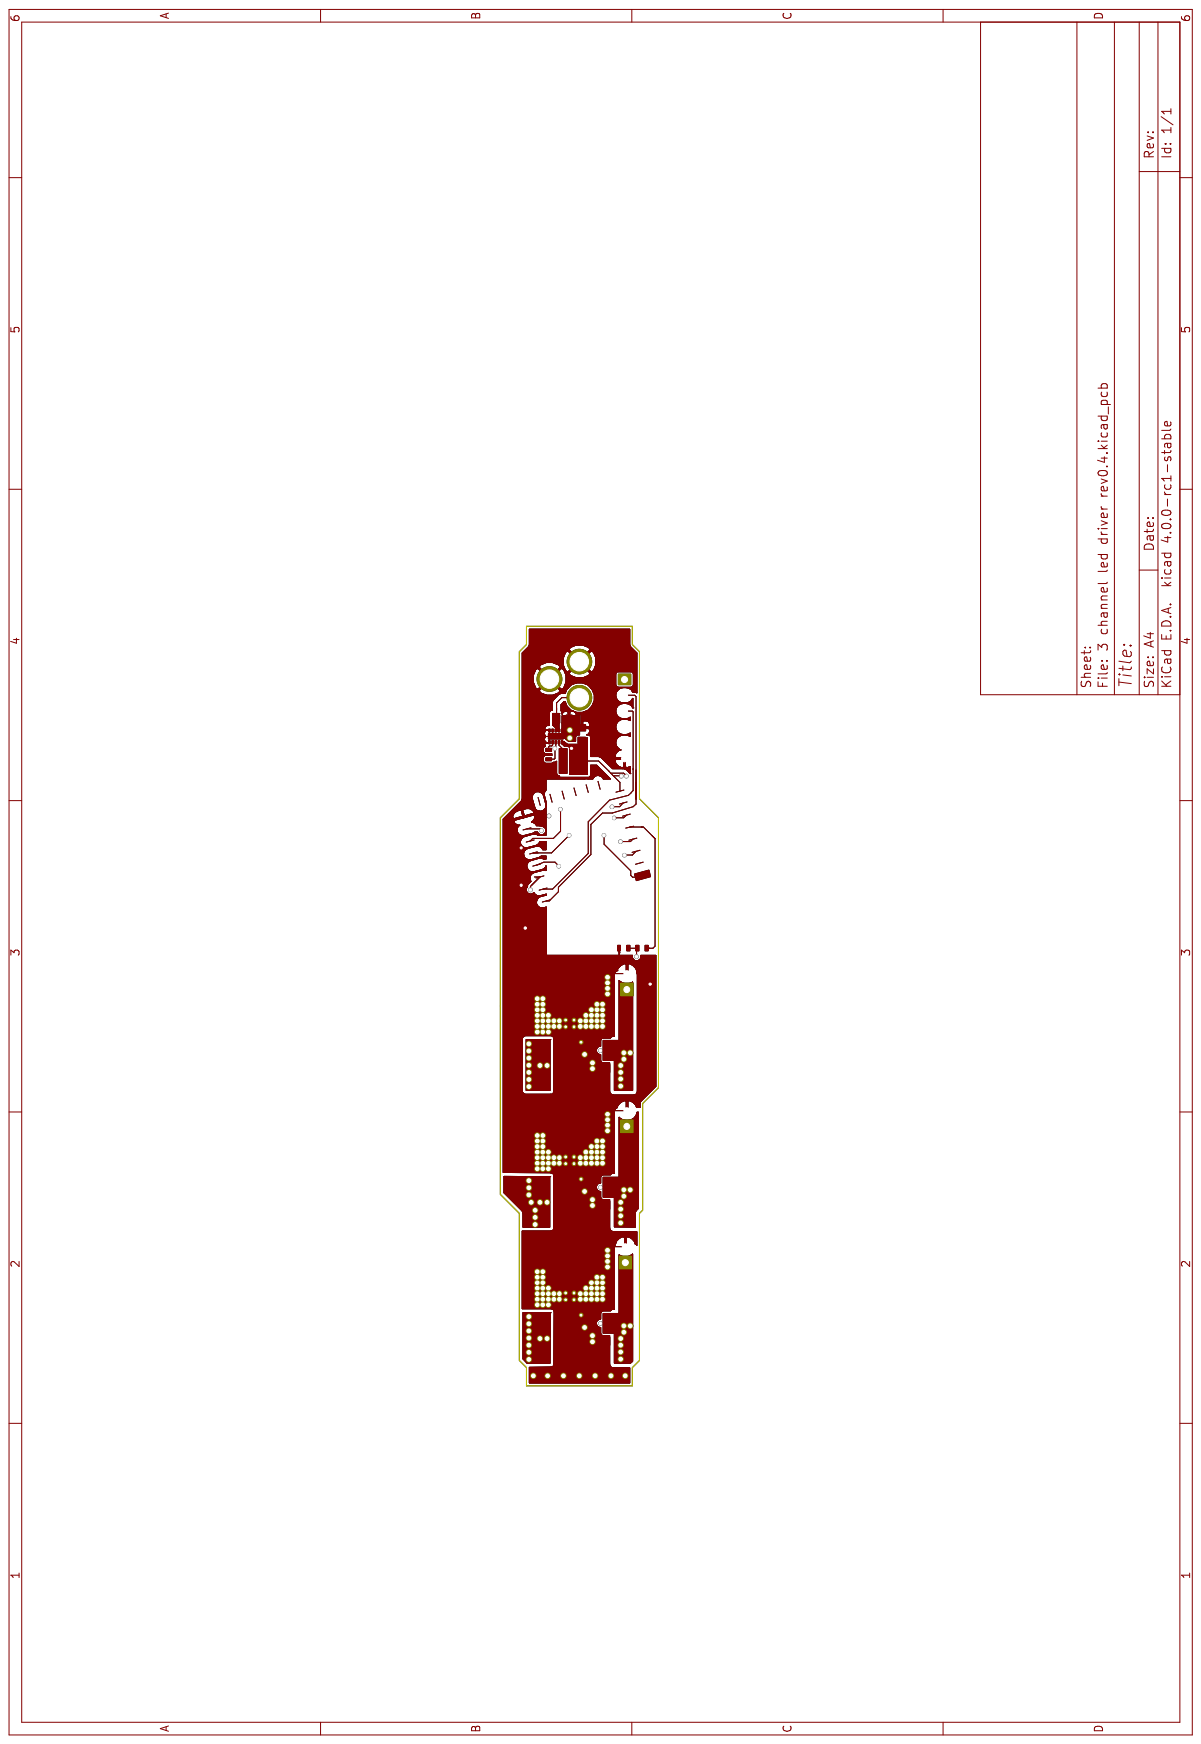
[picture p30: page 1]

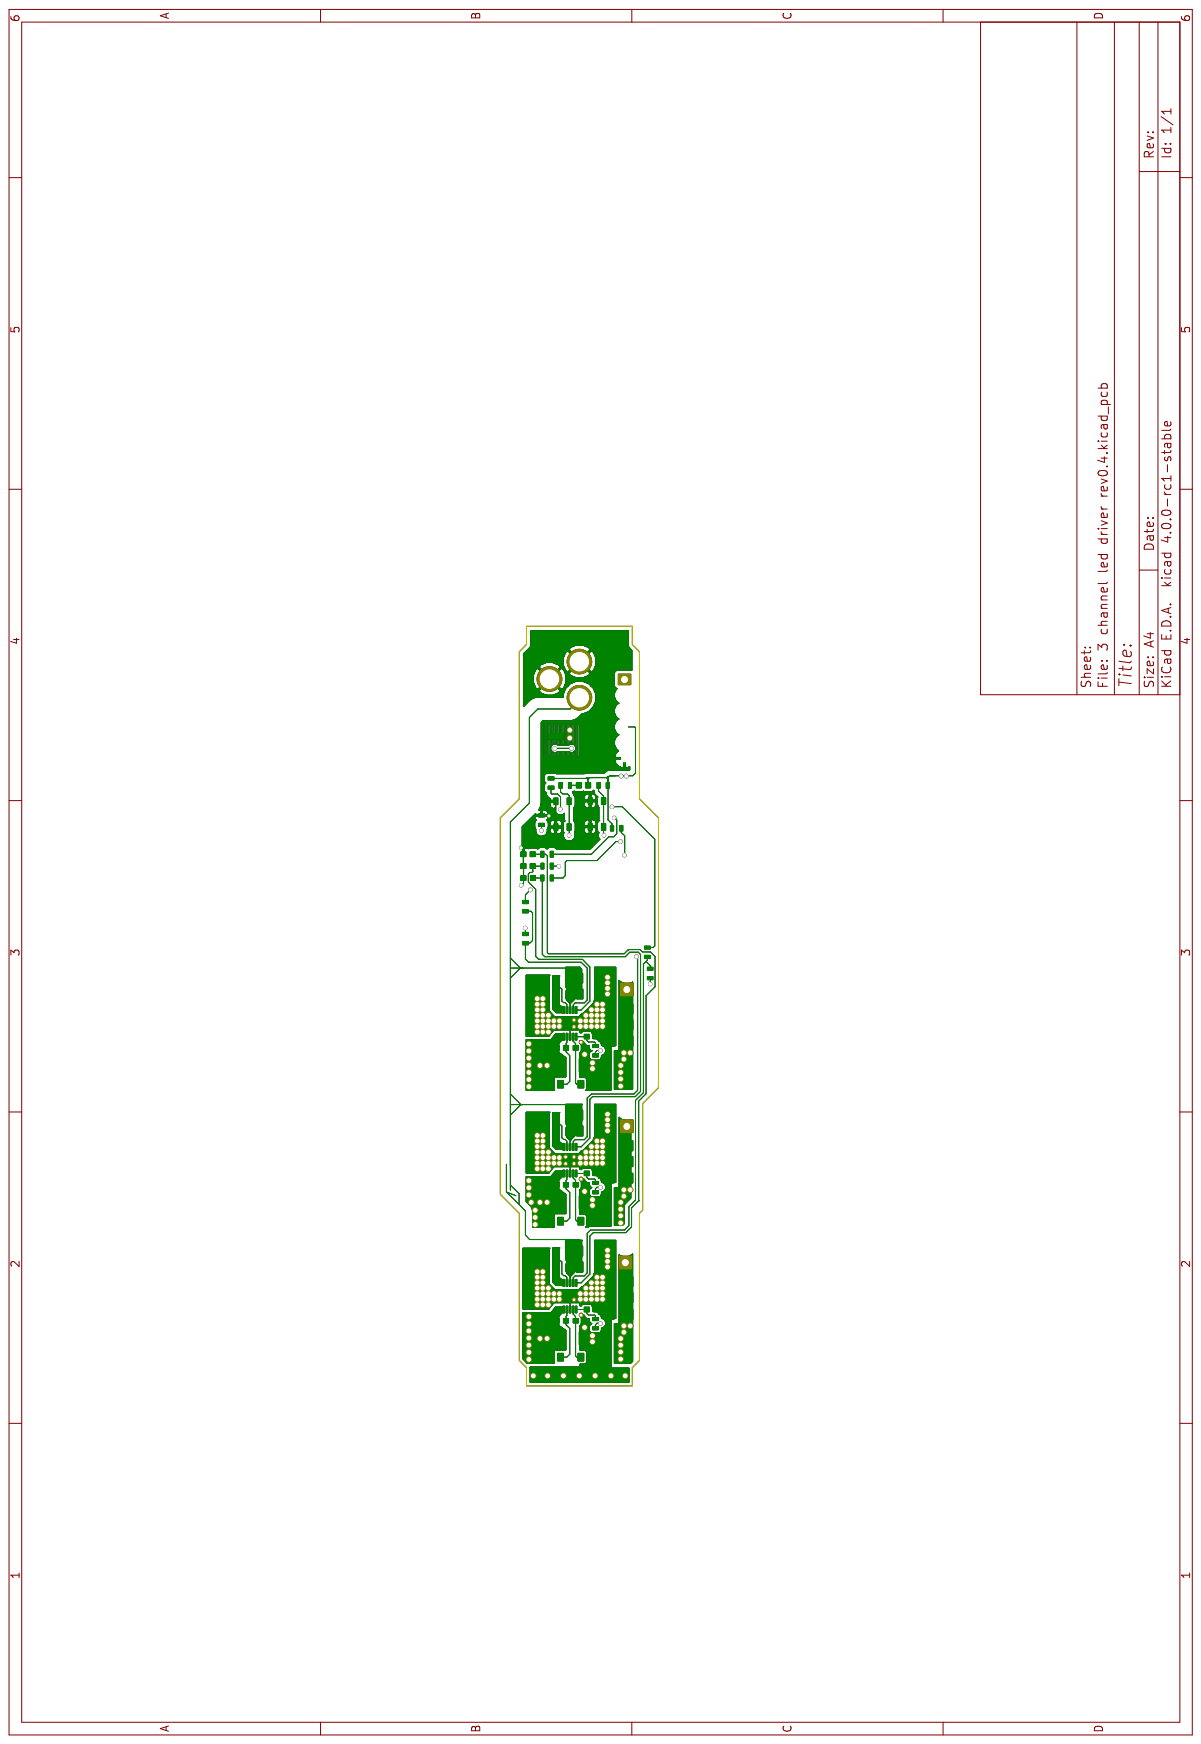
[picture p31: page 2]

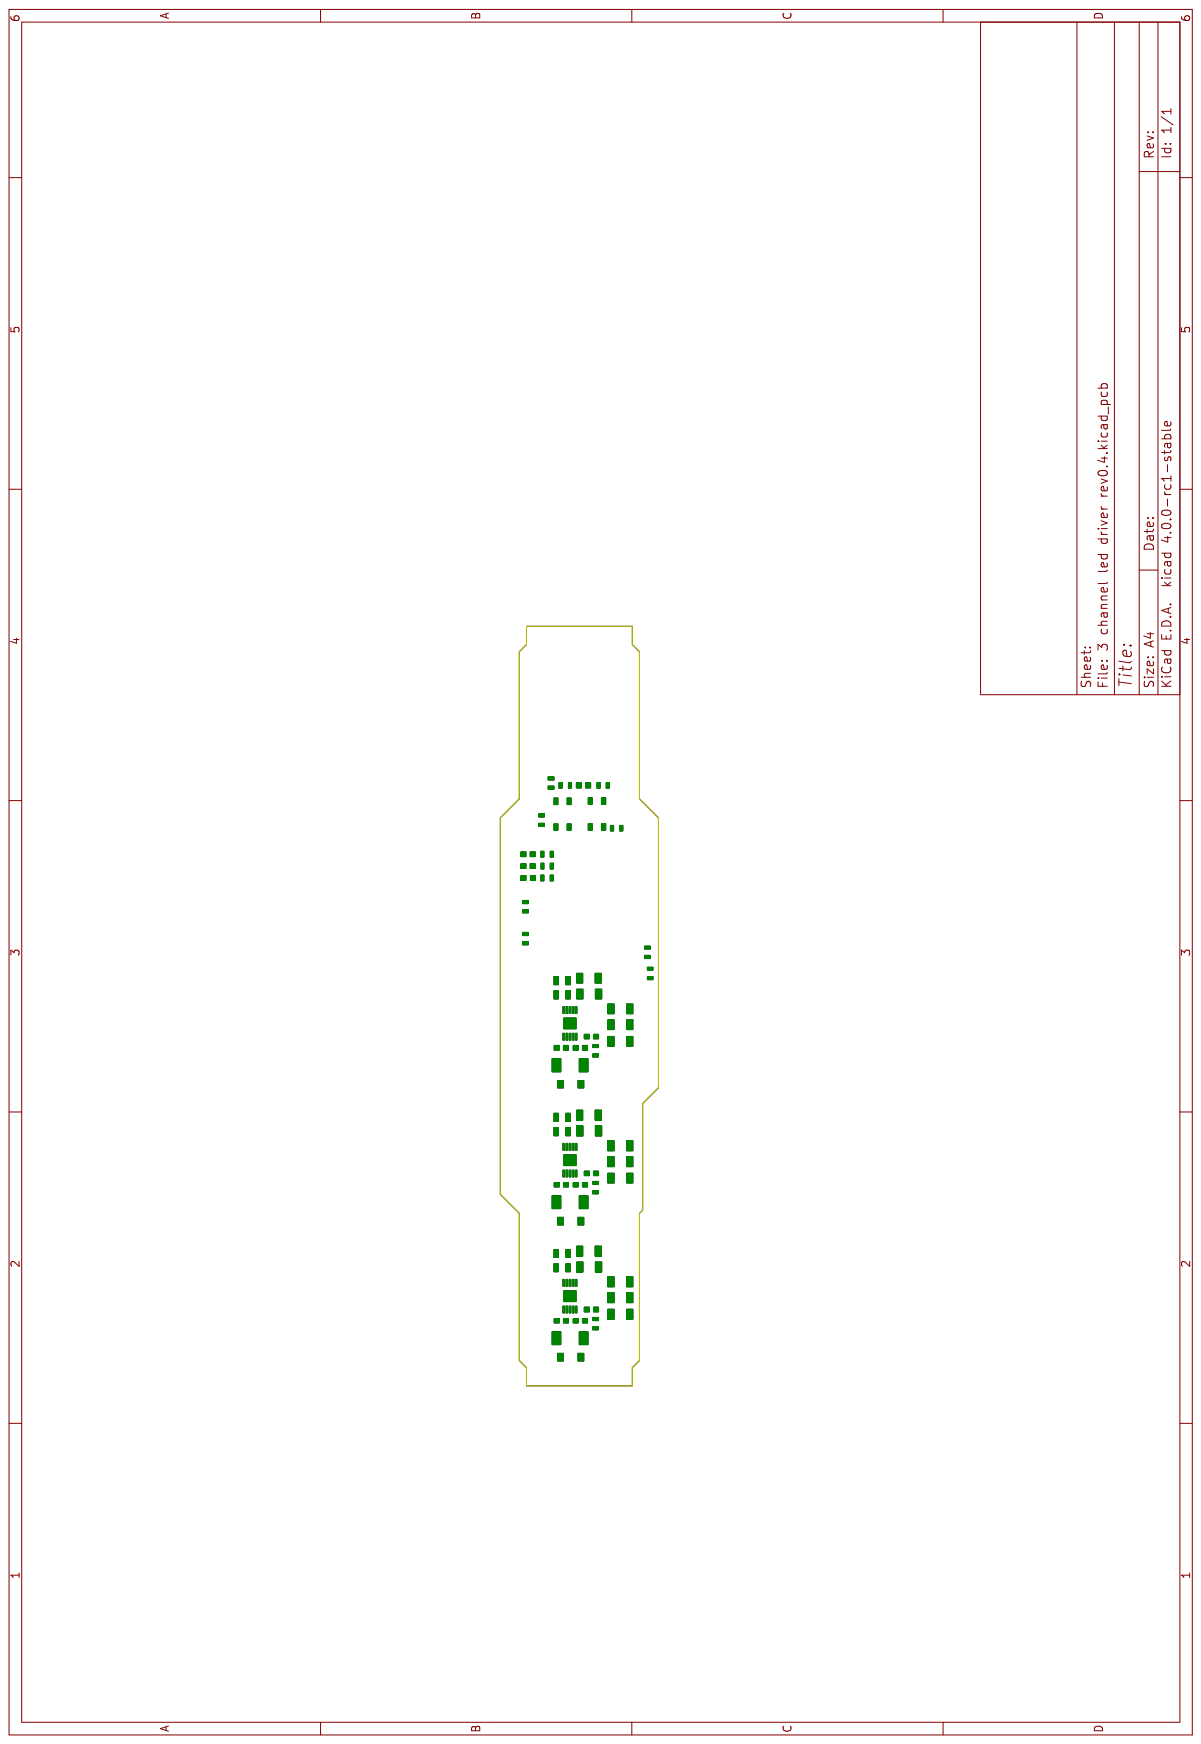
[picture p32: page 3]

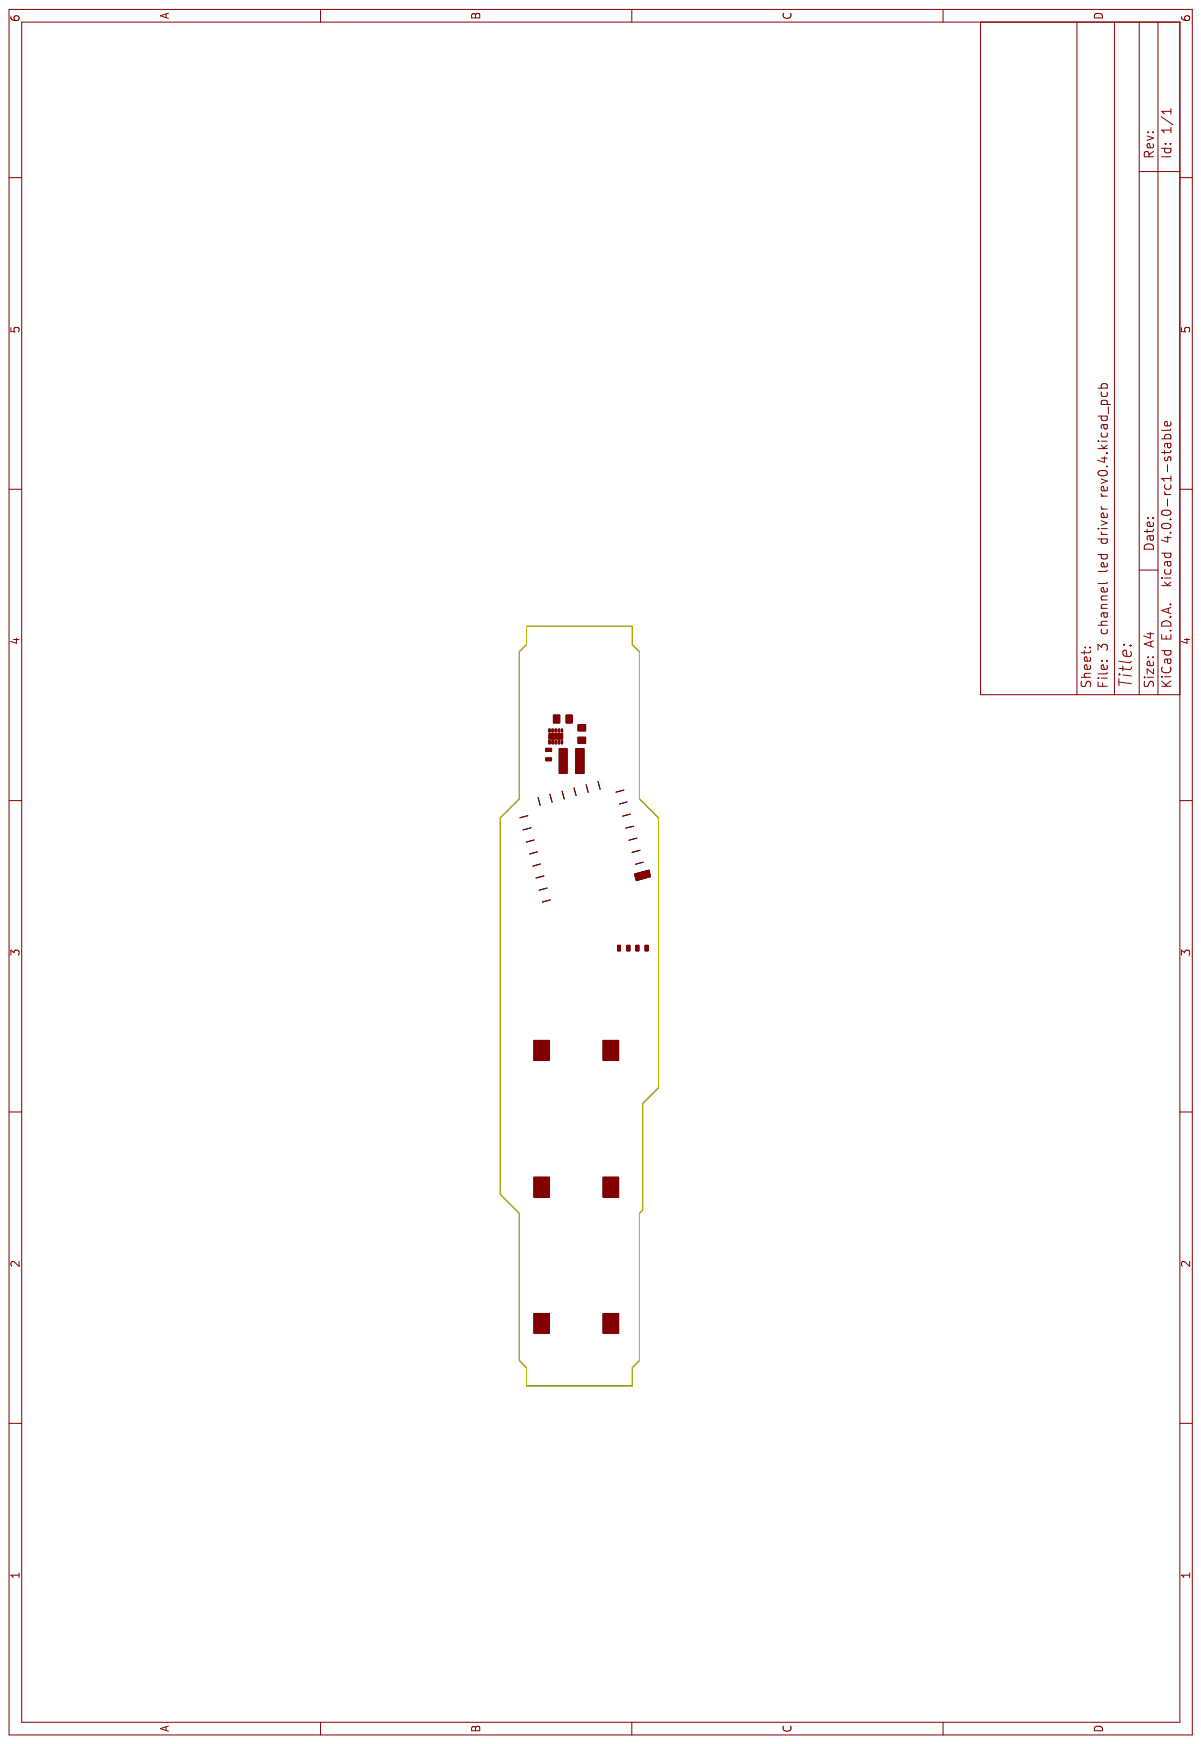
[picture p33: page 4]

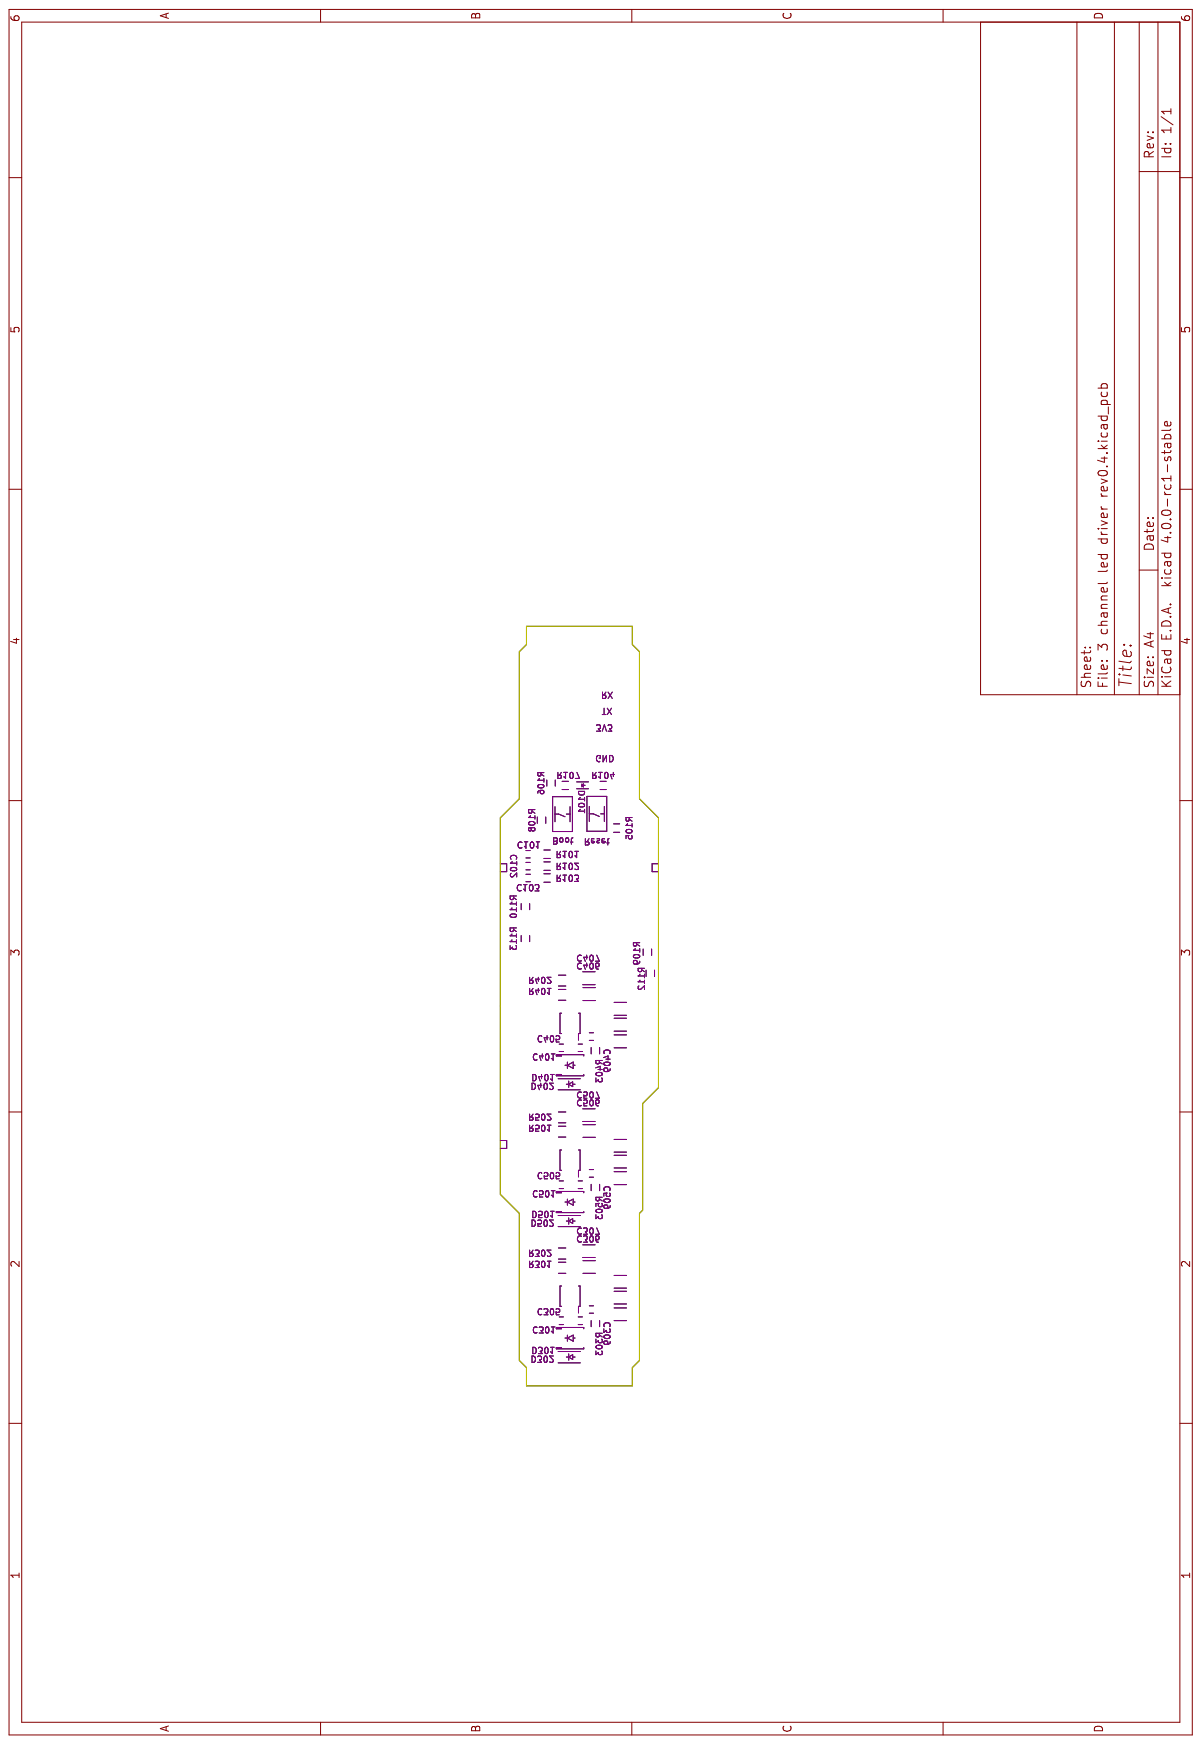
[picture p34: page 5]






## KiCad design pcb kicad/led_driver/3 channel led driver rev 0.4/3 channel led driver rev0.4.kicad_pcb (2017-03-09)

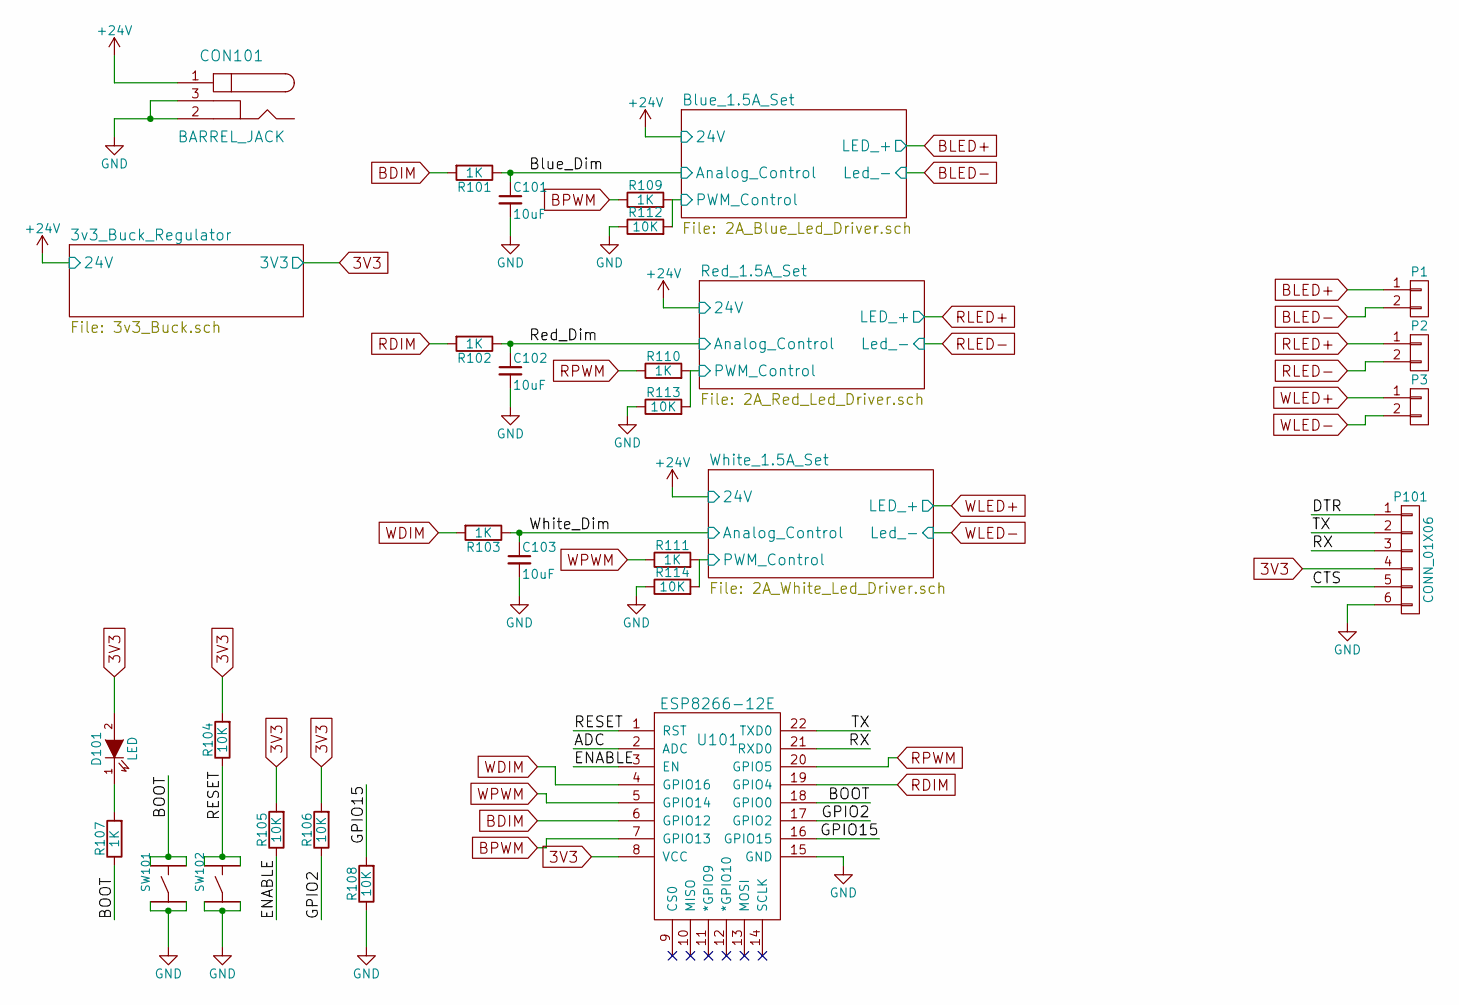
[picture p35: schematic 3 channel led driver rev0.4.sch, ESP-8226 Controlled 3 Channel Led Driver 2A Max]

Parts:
C101, C102, C103: 10uF; C_0603; Manufacturer_Part_# GRM188R60J106KE47D; Mouser_Part_# 81-GRM188R60J106KE7D
CON101: BARREL_JACK; Barrel_Jack_Wurth_694106301002; Manufacturer_Part_# 694106301002; Mouser_Part_# 710-694106301002
D101: LED; LED-0603; Manufacturer_Part_# LTST-C190KRKT; Mouser_Part_# 859-LTST-C190KRKT
P1, P2, P3: CONN_01X02; Pin_Header_Straight_1x02
P101: CONN_01X06; Pin_Header_Straight_1x06
R101, R102, R103, R107, R109, R110, R111: 1K; R_0603
R104, R105, R106, R108, R112, R113, R114: 10K; R_0603
SW101, SW102: TACT_4.2MM; MF_Switches-TACT4.2MM; Manufacturer_Part_# PTS810 SJK 250 SMTR LFS; Mouser_Part_# 611-PTS810SJK250SMTR
U101: ESP8266-12E; ESP-12E; Manufacturer_Part_# ESP8266-12E; Mouser_Part_# 485-2491

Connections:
3V3: D101.2 (A), P101.4, R104.2, R105.2, R106.2, U101.8 (VCC); also elsewhere on the board
+24V: CON101.1; also elsewhere on the board
/ADC: U101.2 (ADC)
/BOOT: R107.1, SW101.P$1, SW101.P$2, U101.18 (GPIO0)
/Blue_1.5A_Set/Analog_Control: C101.1, R101.1; also elsewhere on the board
/Blue_1.5A_Set/PWM_Control: R109.2, R112.2; also elsewhere on the board
/CTS: P101.5
/DTR: P101.1
/ENABLE: R105.1, U101.3 (EN)
/GPIO2: R106.1, U101.17 (GPIO2)
/GPIO15: R108.2, U101.16 (GPIO15)
/RESET: R104.1, SW102.P$1, SW102.P$2, U101.1 (RST)
/RX: P101.3, U101.21 (RXD0)
/Red_1.5A_Set/Analog_Control: C102.1, R102.1; also elsewhere on the board
/Red_1.5A_Set/PWM_Control: R110.2, R113.2; also elsewhere on the board
/TX: P101.2, U101.22 (TXD0)
/White_1.5A_Set/Analog_Control: C103.1, R103.1; also elsewhere on the board
/White_1.5A_Set/PWM_Control: R111.2, R114.2; also elsewhere on the board
BDIM: R101.2, U101.6 (GPIO12)
BLED+: P1.1; also elsewhere on the board
BLED-: C101.2, C102.2, C103.2, CON101.2, CON101.3, P1.2, P2.2, P3.2, P101.6, R108.1, R112.1, R113.1, R114.1, SW101.P$3, SW101.P$4, SW102.P$3, SW102.P$4, U101.15 (GND); also elsewhere on the board
BPWM: R109.1, U101.7 (GPIO13)
RDIM: R102.2, U101.19 (GPIO4)
RLED+: P2.1; also elsewhere on the board
RPWM: R110.1, U101.20 (GPIO5)
WDIM: R103.2, U101.4 (GPIO16)
WLED+: P3.1; also elsewhere on the board
WPWM: R111.1, U101.5 (GPIO14)

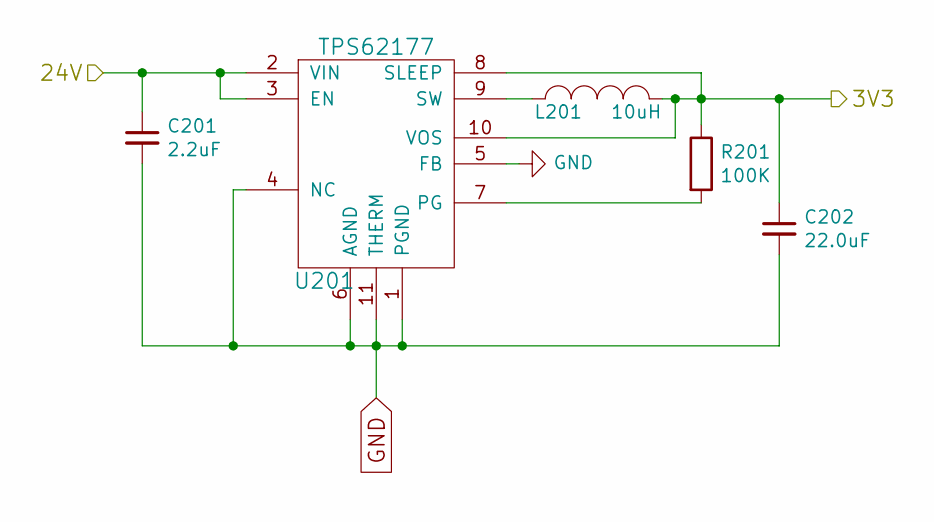
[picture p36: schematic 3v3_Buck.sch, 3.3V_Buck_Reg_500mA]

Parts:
C201: 2.2uF; C_0805; Manufacturer_Part_# GRM21BR61E225KA12L; Mouser_Part_# 81-GRM21R61E225KA12L
C202: 22.0uF; C_0805; Manufacturer_Part_# 81-GRM21R60J226ME39L; Mouser_Part_# 81-GRM21R60J226ME39L
L201: 10uH; VLS4012ET-100M; Manufacturer_Part_# VLS4012ET-100M; Mouser_Part_# 810-VLS4012ET-100M
R201: 100K; R_0603
U201: TPS62177; Manufacturer_Part_# TPS62177DQCR; Mouser_Part_# 595-TPS62177DQCR

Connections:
3V3: C202.1, L201.2, R201.1, U201.8 (SLEEP), U201.10 (VOS); also elsewhere on the board
+24V: C201.1, U201.2 (VIN), U201.3 (EN); also elsewhere on the board
BLED-: C201.2, C202.2, U201.1 (PGND), U201.4 (NC), U201.5 (FB), U201.6 (AGND), U201.11 (THERM); also elsewhere on the board
unnamed: L201.1, U201.9 (SW)
unnamed: R201.2, U201.7 (PG)

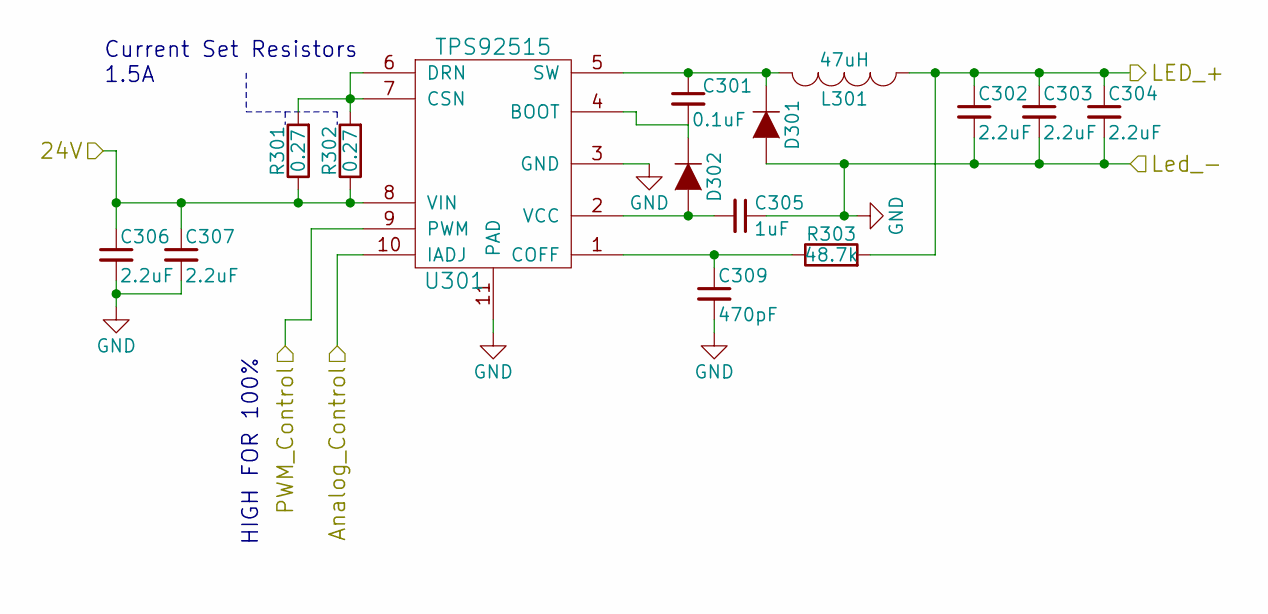
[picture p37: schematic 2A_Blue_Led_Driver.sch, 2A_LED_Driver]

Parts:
C301: 0.1uF; C_0603; Manufacturer_Part_# GCM188R71C104KA37J; Mouser_Part_# 81-GCM188R71C104KA7J
C302, C303, C304, C306, C307: 2.2uF; C_0805; Manufacturer_Part_# GRM21BR61E225KA12L; Mouser_Part_# GRM21BR61E225KA12L
C305: 1uF; C_0603; Manufacturer_Part_# GCM188R71C105KA64D; Mouser_Part_# 81-GCM188R71C105K64D
C309: 470pF; C_0603; Manufacturer_Part_# GRM033R71H471KA12D; Mouser_Part_# 81-GRM033R71H471KA2D
D301: 100V 3A; SOD-128-2; Manufacturer_Part_# PMEG10030ELPX; Mouser_Part_# 771-PMEG10030ELPX
D302: 100V 200mA; SOD-123; Manufacturer_Part_# MMSD4148T1G; Mouser_Part_# 863-MMSD4148T1G
L301: 47uH; MBH12575C; Manufacturer_Part_# MBH12575C-470MA=P3; Mouser_Part_# 81-MBH12575C-470MAP3
R301, R302: 0.27; R_0805; Manufacturer_Part_# KRL1220E-M-R270-F-T5; Mouser_Part_# 754-KRL1220EMR270FT5
R303: 48.7k; R_0603; Manufacturer_Part_# CRCW060348K7FKEA; Mouser_Part_# 71-CRCW0603-48.7K-E3
U301: TPS92515; TPS92515x; Manufacturer_Part_# TPS92515DGQR; Mouser_Part_# 595-TPS92515DGQR

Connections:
+24V: C306.1, C307.1, R301.1, R302.1, U301.8 (VIN); also elsewhere on the board
/Blue_1.5A_Set/Analog_Control: U301.10 (IADJ); also elsewhere on the board
/Blue_1.5A_Set/PWM_Control: U301.9 (PWM); also elsewhere on the board
BLED+: C302.1, C303.1, C304.1, L301.1, R303.2; also elsewhere on the board
BLED-: C302.2, C303.2, C304.2, C305.1, C306.2, C307.2, C309.2, D301.2 (A), U301.3 (GND), U301.11 (PAD); also elsewhere on the board
unnamed: C301.1, D301.1 (K), L301.2, U301.5 (SW)
unnamed: C301.2, D302.1 (K), U301.4 (BOOT)
unnamed: C305.2, D302.2 (A), U301.2 (VCC)
unnamed: C309.1, R303.1, U301.1 (COFF)
unnamed: R301.2, R302.2, U301.6 (DRN), U301.7 (CSN)

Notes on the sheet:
HIGH FOR 100%
Current Set Resistors 1.5A

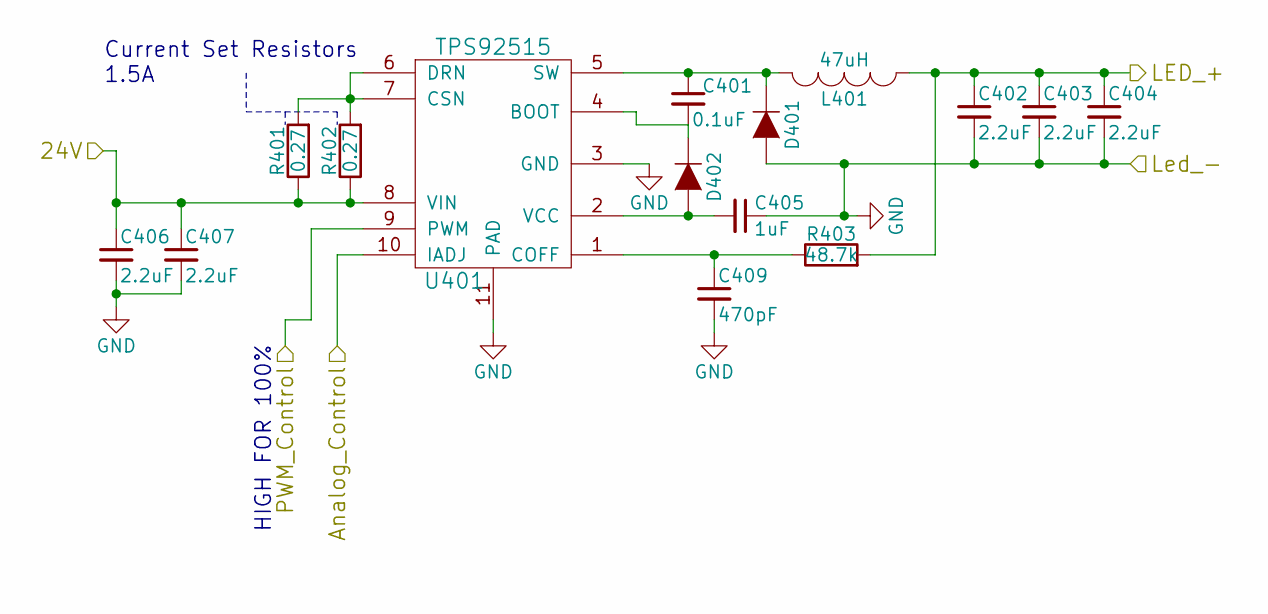
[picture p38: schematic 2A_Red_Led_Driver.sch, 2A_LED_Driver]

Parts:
C401: 0.1uF; C_0603; Manufacturer_Part_# GCM188R71C104KA37J; Mouser_Part_# 81-GCM188R71C104KA7J
C402, C403, C404, C406, C407: 2.2uF; C_0805; Manufacturer_Part_# GRM21BR61E225KA12L; Mouser_Part_# GRM21BR61E225KA12L
C405: 1uF; C_0603; Manufacturer_Part_# GCM188R71C105KA64D; Mouser_Part_# 81-GCM188R71C105K64D
C409: 470pF; C_0603; Manufacturer_Part_# GRM033R71H471KA12D; Mouser_Part_# 81-GRM033R71H471KA2D
D401: 100V 3A; SOD-128-2; Manufacturer_Part_# PMEG10030ELPX; Mouser_Part_# 771-PMEG10030ELPX
D402: 100V 200mA; SOD-123; Manufacturer_Part_# MMSD4148T1G; Mouser_Part_# 863-MMSD4148T1G
L401: 47uH; MBH12575C; Manufacturer_Part_# MBH12575C-470MA=P3; Mouser_Part_# 81-MBH12575C-470MAP3
R401, R402: 0.27; R_0805; Manufacturer_Part_# KRL1220E-M-R270-F-T5; Mouser_Part_# 754-KRL1220EMR270FT5
R403: 48.7k; R_0603; Manufacturer_Part_# CRCW060348K7FKEA; Mouser_Part_# 71-CRCW0603-48.7K-E3
U401: TPS92515; TPS92515x; Manufacturer_Part_# TPS92515DGQR; Mouser_Part_# 595-TPS92515DGQR

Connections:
+24V: C406.1, C407.1, R401.1, R402.1, U401.8 (VIN); also elsewhere on the board
/Red_1.5A_Set/Analog_Control: U401.10 (IADJ); also elsewhere on the board
/Red_1.5A_Set/PWM_Control: U401.9 (PWM); also elsewhere on the board
BLED-: C402.2, C403.2, C404.2, C405.1, C406.2, C407.2, C409.2, D401.2 (A), U401.3 (GND), U401.11 (PAD); also elsewhere on the board
unnamed: C401.1, D401.1 (K), L401.2, U401.5 (SW)
unnamed: C401.2, D402.1 (K), U401.4 (BOOT)
unnamed: C405.2, D402.2 (A), U401.2 (VCC)
unnamed: C409.1, R403.1, U401.1 (COFF)
unnamed: R401.2, R402.2, U401.6 (DRN), U401.7 (CSN)
RLED+: C402.1, C403.1, C404.1, L401.1, R403.2; also elsewhere on the board

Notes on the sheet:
HIGH FOR 100%
Current Set Resistors 1.5A

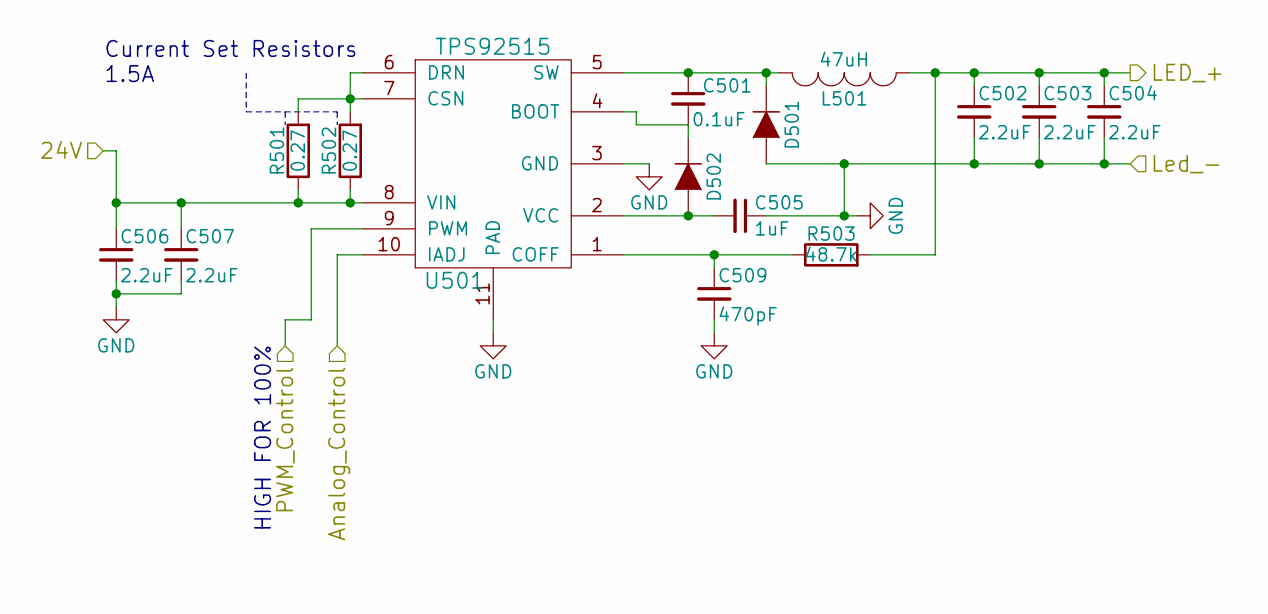
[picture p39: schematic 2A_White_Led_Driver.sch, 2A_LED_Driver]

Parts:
C501: 0.1uF; C_0603; Manufacturer_Part_# GCM188R71C104KA37J; Mouser_Part_# 81-GCM188R71C104KA7J
C502, C503, C504, C506, C507: 2.2uF; C_0805; Manufacturer_Part_# GRM21BR61E225KA12L; Mouser_Part_# GRM21BR61E225KA12L
C505: 1uF; C_0603; Manufacturer_Part_# GCM188R71C105KA64D; Mouser_Part_# 81-GCM188R71C105K64D
C509: 470pF; C_0603; Manufacturer_Part_# GRM033R71H471KA12D; Mouser_Part_# 81-GRM033R71H471KA2D
D501: 100V 3A; SOD-128-2; Manufacturer_Part_# PMEG10030ELPX; Mouser_Part_# 771-PMEG10030ELPX
D502: 100V 200mA; SOD-123; Manufacturer_Part_# MMSD4148T1G; Mouser_Part_# 863-MMSD4148T1G
L501: 47uH; MBH12575C; Manufacturer_Part_# MBH12575C-470MA=P3; Mouser_Part_# 81-MBH12575C-470MAP3
R501, R502: 0.27; R_0805; Manufacturer_Part_# KRL1220E-M-R270-F-T5; Mouser_Part_# 754-KRL1220EMR270FT5
R503: 48.7k; R_0603; Manufacturer_Part_# CRCW060348K7FKEA; Mouser_Part_# 71-CRCW0603-48.7K-E3
U501: TPS92515; TPS92515x; Manufacturer_Part_# TPS92515DGQR; Mouser_Part_# 595-TPS92515DGQR

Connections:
+24V: C506.1, C507.1, R501.1, R502.1, U501.8 (VIN); also elsewhere on the board
/White_1.5A_Set/Analog_Control: U501.10 (IADJ); also elsewhere on the board
/White_1.5A_Set/PWM_Control: U501.9 (PWM); also elsewhere on the board
BLED-: C502.2, C503.2, C504.2, C505.1, C506.2, C507.2, C509.2, D501.2 (A), U501.3 (GND), U501.11 (PAD); also elsewhere on the board
unnamed: C501.1, D501.1 (K), L501.2, U501.5 (SW)
unnamed: C501.2, D502.1 (K), U501.4 (BOOT)
unnamed: C505.2, D502.2 (A), U501.2 (VCC)
unnamed: C509.1, R503.1, U501.1 (COFF)
unnamed: R501.2, R502.2, U501.6 (DRN), U501.7 (CSN)
WLED+: C502.1, C503.1, C504.1, L501.1, R503.2; also elsewhere on the board

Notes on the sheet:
HIGH FOR 100%
Current Set Resistors 1.5A

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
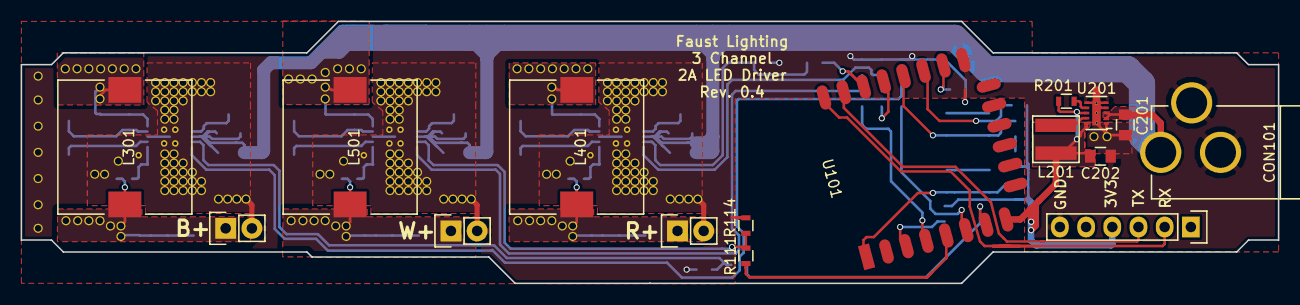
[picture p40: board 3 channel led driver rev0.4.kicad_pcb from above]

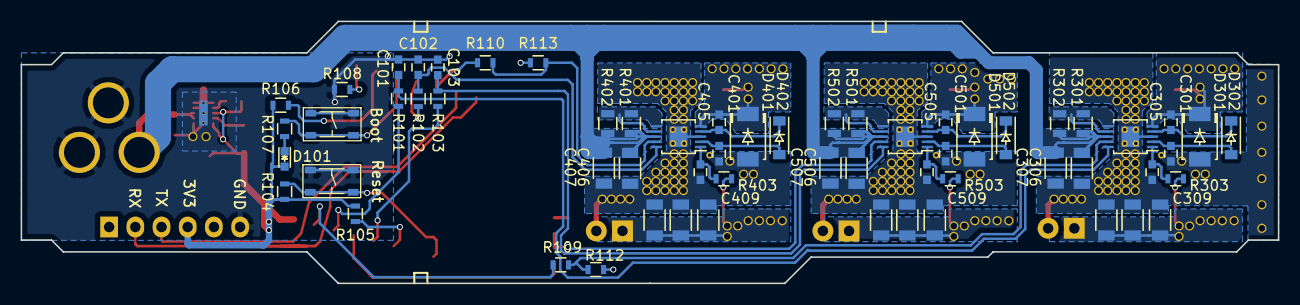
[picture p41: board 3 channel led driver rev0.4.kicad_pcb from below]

Board: 2 copper layers, 121.9 x 25.4 mm, 76 parts (60 on the bottom side), 42 nets.

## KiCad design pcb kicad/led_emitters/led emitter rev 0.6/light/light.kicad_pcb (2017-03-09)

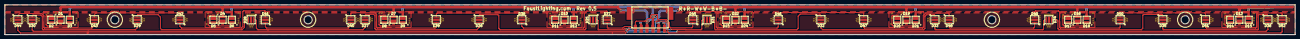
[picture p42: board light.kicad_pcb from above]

Board: 2 copper layers, 551.2 x 12.7 mm, 53 parts (0 on the bottom side), 47 nets.

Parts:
D1, D2, D3, D4, D5, D6, D7, D8, D9, D10, D11, D12, D13, D14, D15, D16, D17, D18, D19, D20, D21, D22, D23, D24: Led_Small; MP3030
D25, D26, D27, D28, D29, D30, D31, D32, D33, D34, D35, D36: Blue 450nm; Blue_450nm
D37, D38, D39, D40, D41, D42, D43, D44, D45, D46, D47, D48, D49, D50, D51, D52: Deep Red 660nm; Deep_Red_660nm
P1: CONN_02X03; 1814676

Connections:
B+: D25.2, D31.2, P1.5
B-: D30.1, D36.1, P1.6
unnamed: D1.1, D2.2
unnamed: D2.1, D3.2
unnamed: D4.1, D5.2
unnamed: D5.1, D6.2
unnamed: D7.1, D8.2
unnamed: D8.1, D9.2
unnamed: D10.1, D11.2
unnamed: D11.1, D12.2
unnamed: D13.1, D14.2
unnamed: D14.1, D15.2
unnamed: D16.1, D17.2
unnamed: D17.1, D18.2
unnamed: D19.1, D20.2
unnamed: D20.1, D21.2
unnamed: D22.1, D23.2
unnamed: D23.1, D24.2
unnamed: D25.1, D26.2
unnamed: D26.1, D27.2
unnamed: D27.1, D28.2
unnamed: D28.1, D29.2
unnamed: D29.1, D30.2
unnamed: D31.1, D32.2
unnamed: D32.1, D33.2
unnamed: D33.1, D34.2
unnamed: D34.1, D35.2
unnamed: D35.1, D36.2
unnamed: D37.1, D38.2
unnamed: D38.1, D39.2
unnamed: D39.1, D40.2
unnamed: D40.1, D41.2
unnamed: D41.1, D42.2
unnamed: D42.1, D43.2
unnamed: D43.1, D44.2
unnamed: D45.1, D46.2
unnamed: D46.1, D47.2
unnamed: D47.1, D48.2
unnamed: D48.1, D49.2
unnamed: D49.1, D50.2
unnamed: D50.1, D51.2
unnamed: D51.1, D52.2
R+: D37.2, D45.2, P1.1
R-: D44.1, D52.1, P1.2
THERMAL: D25.3, D26.3, D27.3, D28.3, D29.3, D30.3, D31.3, D32.3, D33.3, D34.3, D35.3, D36.3, D37.3, D38.3, D39.3, D40.3, D41.3, D42.3, D43.3, D44.3, D45.3, D46.3, D47.3, D48.3, D49.3, D50.3, D51.3, D52.3
W+: D1.2, D4.2, D7.2, D10.2, D13.2, D16.2, D19.2, D22.2, P1.3
W-: D3.1, D6.1, D9.1, D12.1, D15.1, D18.1, D21.1, D24.1, P1.4

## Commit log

2017-03-09 Added PCB files
    [2A_Blue_Led_Driver.sch, 2A_Red_Led_Driver.sch, 2A_White_Led_Driver.sch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]
2017-03-11 Added Readme to PCB Folder
2017-03-16 Updated ASM1001 to Rev 0.2, Added SolidWorks files
    [BKT1002.SLDPRT, COV1001.SLDPRT, COV1002.SLDPRT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]
